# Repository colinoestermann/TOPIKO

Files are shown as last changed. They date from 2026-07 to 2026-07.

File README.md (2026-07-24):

<div align="center">

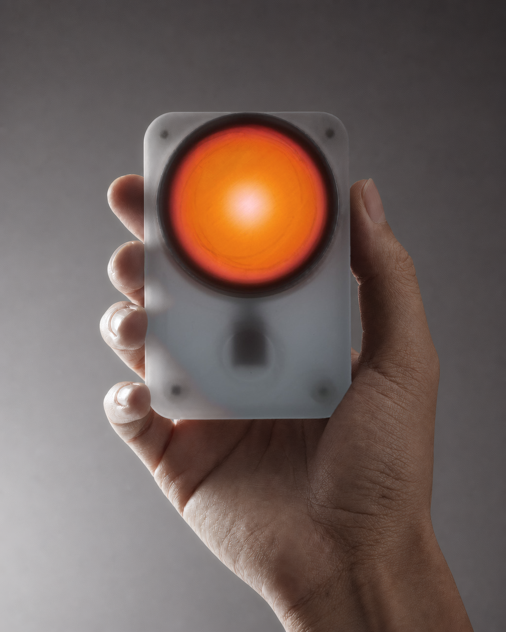
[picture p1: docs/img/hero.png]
TOPIKO


# TOPIKO

**Ein offline Sprachnotiz-Gerät auf Basis von Edge-KI — ohne Cloud, ohne Konto, ohne Abo.**




</div>

---

## Was ist TOPIKO?

TOPIKO ist ein handtellergroßes Gerät, in das man kurze Sprachnotizen spricht. Diese werden **vollständig lokal** in Text umgewandelt und von einem kleinen Sprachmodell in Kategorien wie Termin, To-do, Erinnerung, Idee oder Tagebuch einsortiert — es verlässt kein einziges Byte das eigene Netzwerk. Kein Cloud-Dienst, kein Mikrofon, das dauerhaft mithört, keine Konten.

Das Projekt entstand im Rahmen einer Masterarbeit zum Thema *„Edge-KI als nachhaltige Alternative zu Cloud-KI"* und ist als offene Bauanleitung gedacht: 3D-Daten, Firmware, Serversoftware und Dokumentation sind frei verfügbar.

Das Interface ist bewusst **wortlos**: Das Display strahlt durch eine transluzente Gehäuseschicht, ein weicher Lichtkörper reagiert in Echtzeit auf die Stimme, und Zustände werden nur über Farbe und Bewegung ausgedrückt.

## Systemüberblick

TOPIKO besteht aus zwei Komponenten, die über WLAN miteinander sprechen:

| Komponente | Hardware | Aufgabe |
|---|---|---|
| **Handheld** | Waveshare ESP32-S3-Touch-AMOLED-1.75 | Aufnahme per Touch, Visualisierung, Upload der Sprachnotiz |
| **Dock** | Arduino UNO Q (Debian Linux) | Transkription (Whisper) + Klassifizierung (lokales LLM) |

```
   ┌──────────────┐    WLAN / WAV-Upload     ┌────────────────────┐
   │   Handheld    │ ───────────────────────▶ │        Dock         │
   │  ESP32-S3     │                           │     Arduino UNO Q   │
   │  AMOLED,Mikro │ ◀─────────────────────── │  Whisper + LLM      │
   └──────────────┘   JSON-Ergebnis zurück     └────────────────────┘
```

Das Handheld nimmt auf Tastendruck bis zu 20 s Audio auf, legt es in eine lokale Warteschlange und lädt es hoch, sobald das Dock erreichbar ist. Das Dock transkribiert mit `whisper.cpp` und klassifiziert mit einem kleinen, quantisierten Sprachmodell (llama.cpp). Das Ergebnis kommt als JSON zurück und wird am Gerät über einen Kategorie-Farbpuls angezeigt.

## Funktionen

- **100 % offline** — Transkription und Klassifizierung laufen lokal auf dem Dock.
- **Push-to-talk** — Touch halten, sprechen, loslassen. Kein Wake-Word, kein Dauerlauschen.
- **Wortloses Licht-Interface** — der Lichtkörper atmet mit der Stimme; Kategorien und Zustände über Farbe.
- **Robuste Warteschlange** — Notizen werden lokal gepuffert und automatisch hochgeladen, sobald das Dock da ist.
- **Stromsparend** — Deep-Sleep nach Inaktivität, konfigurierter AXP2101-Laderegler.
- **Offene Hardware** — 3D-druckbares Gehäuse, Standard-Bauteile, unter ~100 €.

## Repo-Struktur

```
topiko/
├── firmware/topiko_handheld/   ESP32-S3-Firmware (Arduino) inkl. ES7210/ES8311-Treiber
├── software/                   Dock-Software für den Arduino UNO Q (Flask + Whisper + LLM)
├── models/                     Bezug der KI-Modelle (Whisper + TOPIKO-Sprachmodell) + Download-Skript
├── hardware/
│   ├── 3d/                     Druckbare STL (Gehäuse Ober-/Unterteil)
│   └── cad/                    CAD-Quelldateien (STEP, alle Bauteile)
├── docs/
│   ├── aufbau.md               Hardware-Aufbau: drucken, montieren, flashen
│   ├── software-installation.md  Dock einrichten (Whisper, LLM, App)
│   └── TOPIKO_Anleitung_IKEA.pdf  Bebilderte Kurz-Bauanleitung
└── media/                      Fotos, Renderings, Logo
```

## Schnellstart

1. **Hardware bauen** → [`docs/aufbau.md`](docs/aufbau.md): Gehäuse drucken, Bauteile montieren, Firmware flashen.
2. **Dock einrichten** → [`docs/software-installation.md`](docs/software-installation.md): Whisper + Sprachmodell + App auf dem UNO Q installieren.
3. Handheld einschalten, WLAN/Dock verbinden, Touch halten und sprechen.

## Stückliste (Kurzfassung)

| Bauteil | Hinweis |
|---|---|
| Waveshare ESP32-S3-Touch-AMOLED-1.75 | Handheld-Rechner mit Display, Mikro-Array, Touch, AXP2101 |
| Arduino UNO Q (2 GB) | Dock, führt Whisper + LLM aus |
| LiPo-Akku 3,7 V (~320–500 mAh) | flach, für den mobilen Betrieb |
| Lautsprecher (MX1.25) | Bestätigungstöne |
| TTP223 Touch-Sensor | Auslöser im Gehäuse |
| Gewindeeinsätze M2.5 + Schrauben M2.5×7 | Verschraubung |
| Transluzentes + opakes PLA | Gehäuse (Display scheint durch) |

Detaillierte Liste und Montage: [`docs/aufbau.md`](docs/aufbau.md).

## Lizenz

- **Software / Firmware:** [MIT](LICENSE)
- **Hardware, 3D-Daten, Dokumentation:** [CC BY-SA 4.0](LICENSE-hardware.md)

Kurz: frei nutzen, verändern und weitergeben. Bei Hardware/Doku bitte Namensnennung und Weitergabe unter gleichen Bedingungen.

---

<div align="center">
<sub>TOPIKO — Edge-KI als nachhaltige Alternative zu Cloud-KI.</sub>
</div>

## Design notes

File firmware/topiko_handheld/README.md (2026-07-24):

# TOPIKO Handheld-Firmware — Setup & Test

Board: **Waveshare ESP32-S3-Touch-AMOLED-1.75**
Funktion: Taste → 5 s Aufnahme → WAV per WLAN an das UNO-Q-Dock (`/classify`) → JSON-Ergebnis auf dem AMOLED.

## 1. Dateien in den Sketch-Ordner legen
Dieser Ordner braucht neben `topiko_handheld.ino` noch den ES8311-Treiber aus dem Waveshare-Beispiel:
- `es8311.c` und `es8311.h` aus dem Repo `waveshareteam/ESP32-S3-Touch-AMOLED-1.75`,
  Pfad `examples/Arduino-v3.3.5/examples/08_ES8311/` — beide Dateien hierher kopieren.

## 2. Arduino-IDE
- Boardpaket **arduino-esp32 Core ≥ 3.1.0** (Beispiele sind für 3.3.5).
- Board: **ESP32S3 Dev Module**
- **PSRAM: OPI PSRAM** (zwingend — der Audiopuffer liegt im PSRAM)
- Flash Size: **16MB**, USB CDC On Boot: **Enabled**
- Bibliotheken (Bibliotheksverwalter): **GFX Library for Arduino**, **ArduinoJson** (v7).
  `ESP_I2S` ist Teil des Cores.

## 3. Konfiguration im Sketch ausfüllen
```
#define WIFI_SSID  "DEIN_WLAN"
#define WIFI_PASS  "DEIN_PASSWORT"
#define DOCK_IP    "192.168.2.86"   // IP des UNO Q im selben WLAN
```

## 4. Dock prüfen (läuft bereits)
Der Endpunkt ist auf dem UNO Q aktiv. Schnelltest von einem Rechner im selben Netz:
```
curl -F "audio=@irgendeine_16k_mono.wav" http://192.168.2.86:5000/classify
```
Antwort ist JSON mit `transcript`, `result`, `whisper_time`, `llm_time`.

## 5. Auf dem Board zu verifizieren (kann ich blind nicht testen)
Diese Stellen sind im Code mit `VERIFY` markiert:
1. **Mikrofon-Datenpin (wichtigste Stelle):** Die DI/DO-Benennung ist im Waveshare-Repo widersprüchlich. Wenn die Aufnahme **stumm** ist, in `setup()` bei `i2s.setPins(...)` die Argumente **PIN_DI und PIN_DO tauschen**.
2. **Mikrofon-Typ:** `es8311_microphone_config(h, false)` = analoges Mikro. Falls kein Signal, auf `true` (digital) testen. Sollte das Mic-Array über den **ES7210** laufen, muss dieser zusätzlich initialisiert werden (dann Bescheid geben).
3. **Kanal:** Mono nimmt den linken Kanal (`s[i*2]`). Bei Stille/Rauschen ggf. `s[i*2+1]`.
4. **Mic-Gain:** `MIC_GAIN` (Default 30 dB) bei zu leiser/übersteuerter Aufnahme anpassen.
5. **Auslöser-Taste:** Default ist die **BOOT-Taste (GPIO0)**. Für einen eigenen Gehäuse-Taster `BTN_PIN` auf den verwendeten GPIO setzen.
6. **AMOLED-Stromversorgung:** Das Hello-World-Beispiel des Boards treibt das Display ohne PMU-Code, daher kein AXP2101-Init nötig. Falls das Display dunkel bleibt, AXP2101 per `XPowersLib` `power.begin(Wire, AXP2101_SLAVE_ADDRESS, 15, 14)` ergänzen.

## 6. Erwarteter Ablauf
Start → „Bereit · Taste = Notiz" → Taste drücken → „Aufnahme… sprich jetzt" (5 s) → „Verarbeite…" (~50 s) → Anzeige von `type`, `title` und Transkript.

## Status
Firmware ist vollständig geschrieben, aber **noch nicht auf dem Gerät getestet** (kein Board im Zugriff). Erwartbar treffsicher: WLAN, Multipart-Upload, JSON, Display. Erfahrungsgemäß braucht der **Audio-Aufnahmepfad** (Punkt 1–3) eine kurze Hardware-Iteration.

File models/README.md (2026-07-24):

# KI-Modelle

Das **Dock** benötigt zwei Modelle. Beide sind zu groß fürs git-Repo und werden
separat geladen. Das Skript [`download-models.sh`](download-models.sh) holt beide
an die richtigen Stellen.

## 1. Whisper — Transkription

`ggml-small-q4_0.bin`, ein Standardmodell von whisper.cpp. Wird direkt über
whisper.cpp geladen:

```bash
cd ~/whisper.cpp && ./models/download-ggml-model.sh small-q4_0
```

Zielpfad: `~/whisper.cpp/models/ggml-small-q4_0.bin`

## 2. TOPIKO-Sprachmodell — Klassifizierung

`LFM2.5-350M-TOPIKO-Q4_K_M.gguf` — ein auf **LFM2.5-350M** feinjustiertes,
quantisiertes Sprachmodell, das den transkribierten Text in die TOPIKO-Kategorien
(Termin, To-do, Erinnerung, Idee, Tagebuch) einsortiert. Gehostet auf Hugging Face:

> **➡ Download: https://huggingface.co/colin18054/TOPIKO-LFM2.5-350M-GGUF**

Nach dem Download ablegen unter:

```
~/models/LFM2.5-350M-TOPIKO-Q4_K_M.gguf
```

Der Pfad entspricht `GGUF_PATH` in [`../software/topiko_uno_q_app.py`](../software/topiko_uno_q_app.py).

## Beides auf einmal laden

```bash
bash download-models.sh
```

> Vorher im Skript den Platzhalter `HF_REPO` durch das echte Hugging-Face-Repo ersetzen.

---

## Für Maintainer: Modell auf Hugging Face veröffentlichen

Das feinjustierte Modell liegt auf dem Dock unter `~/models/`. Von dort einmalig
hochladen:

```bash
pip install -U "huggingface_hub[cli]"
huggingface-cli login                     # Token von huggingface.co/settings/tokens (Rolle: Write)
huggingface-cli upload colin18054/TOPIKO-LFM2.5-350M-GGUF \
  ~/models/LFM2.5-350M-TOPIKO-Q4_K_M.gguf \
  LFM2.5-350M-TOPIKO-Q4_K_M.gguf
```

Das Modell ist bereits veröffentlicht unter
`https://huggingface.co/colin18054/TOPIKO-LFM2.5-350M-GGUF`.

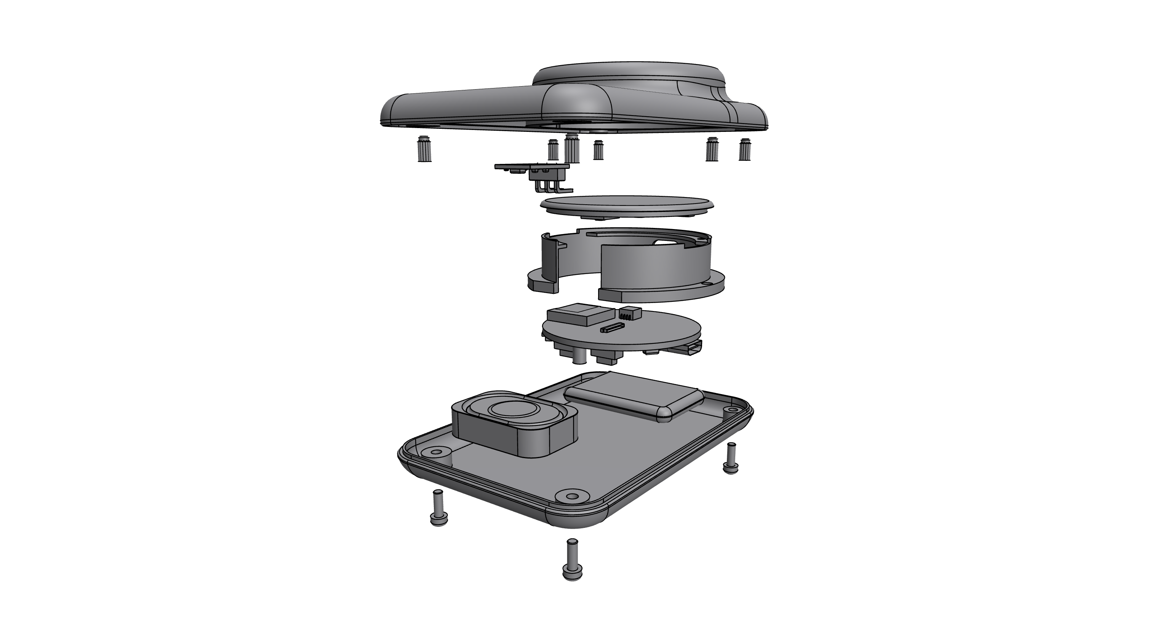
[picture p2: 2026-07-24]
docs/img/Explosionsansicht.png

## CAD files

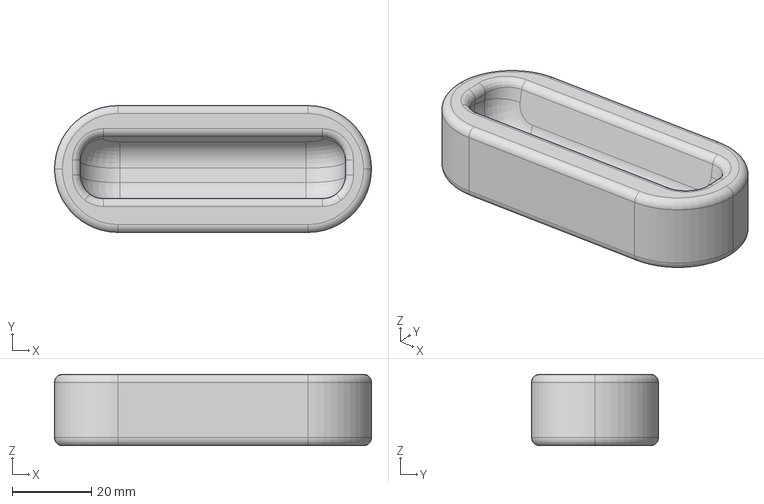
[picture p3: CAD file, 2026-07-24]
hardware/3d/TOPIKO_DOCK_1.0.step
80.0 x 32.0 x 18.0 mm

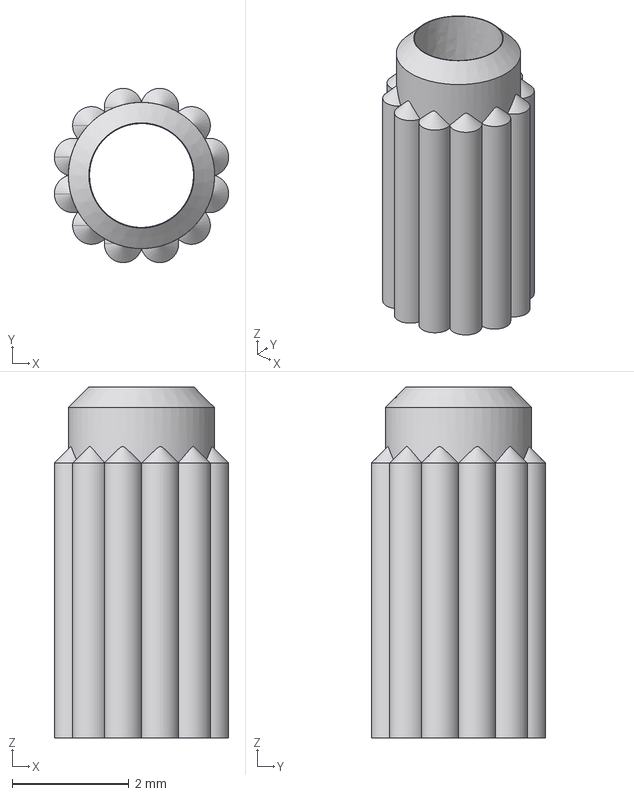
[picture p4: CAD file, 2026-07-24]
hardware/cad/Gewindeeinsatz_M2.5.step
2.98 x 2.98 x 6.00 mm

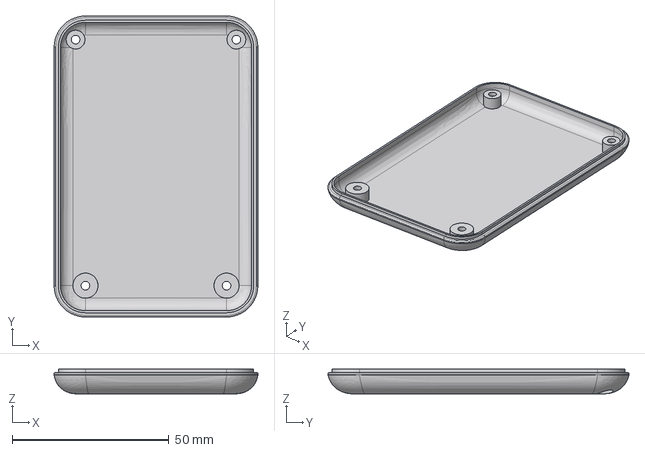
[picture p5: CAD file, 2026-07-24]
hardware/3d/Unterteil.step
65.0 x 96.0 x 7.90 mm

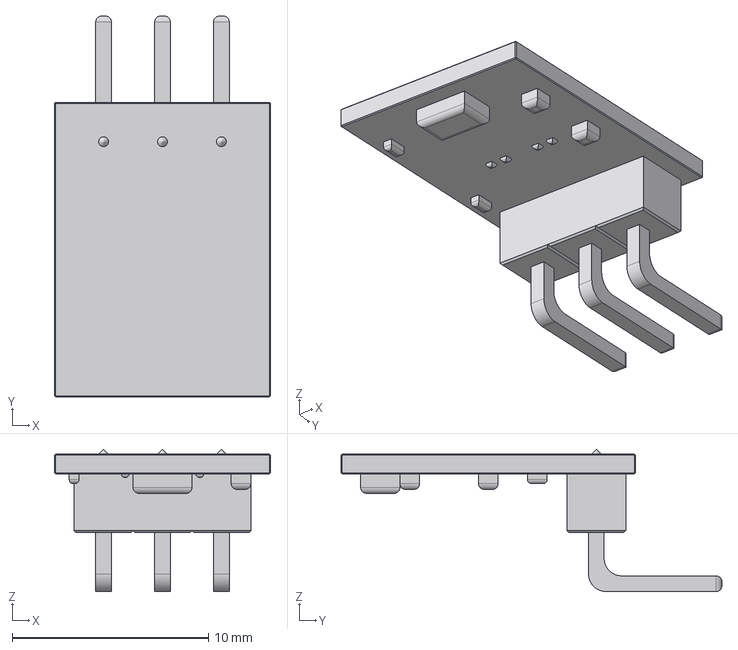
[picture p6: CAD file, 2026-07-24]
hardware/cad/Touchsensor.step
11.0 x 19.4 x 7.24 mm

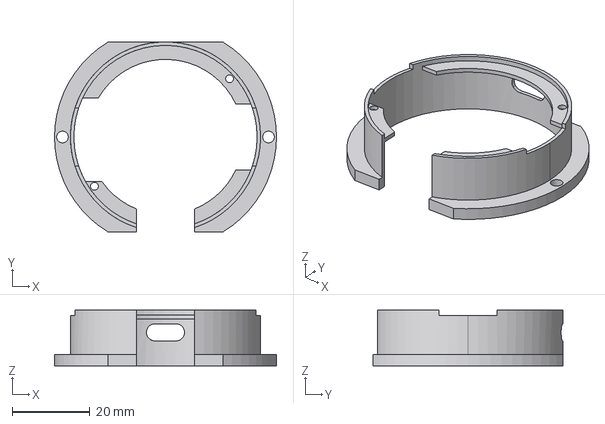
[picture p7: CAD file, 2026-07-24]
hardware/3d/Gehäuseeinsatz.step
57.2 x 49.0 x 14.3 mm

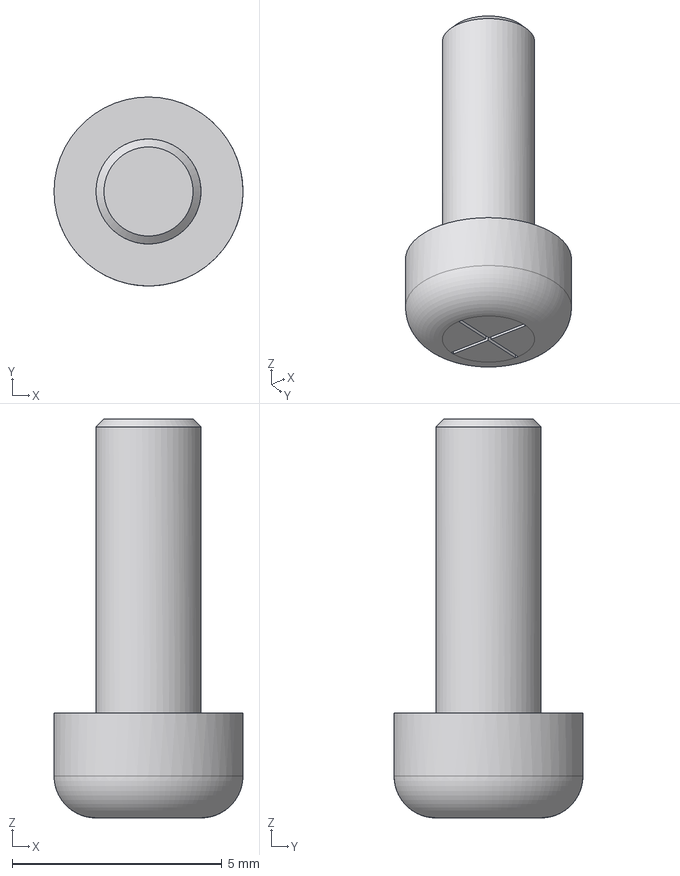
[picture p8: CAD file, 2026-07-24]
hardware/cad/Schraube_M2.5x7.step
4.50 x 4.50 x 9.50 mm

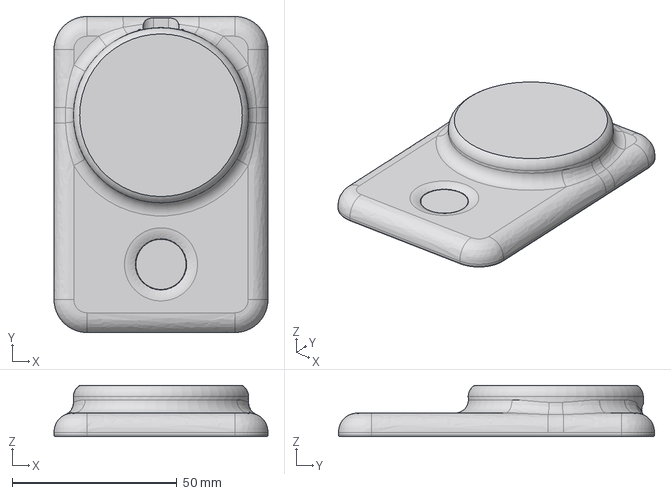
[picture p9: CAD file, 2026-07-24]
hardware/3d/Oberteil.step
65.0 x 96.0 x 15.6 mm

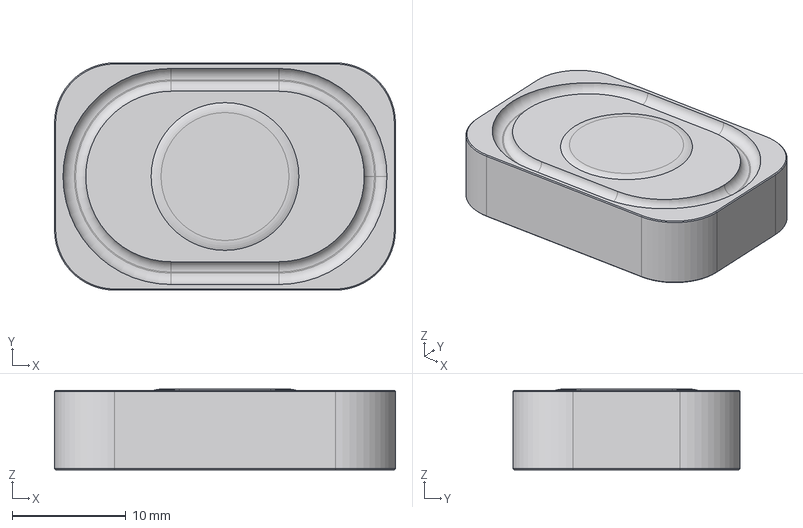
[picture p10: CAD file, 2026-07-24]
hardware/cad/Lautsprecher.step
30.0 x 20.0 x 7.10 mm

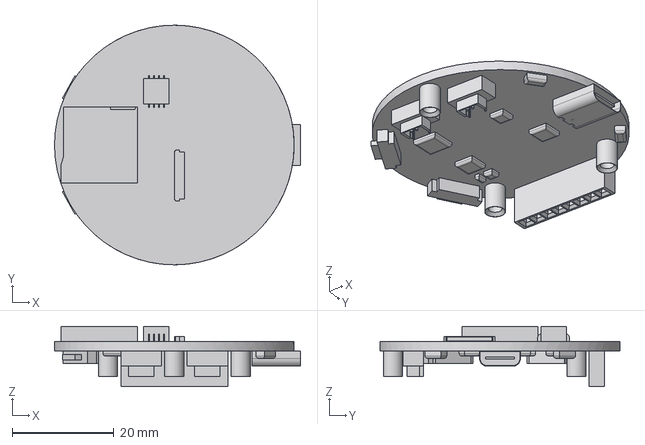
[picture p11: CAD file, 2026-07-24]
hardware/cad/ESP-Board.step
48.2 x 47.0 x 11.8 mm

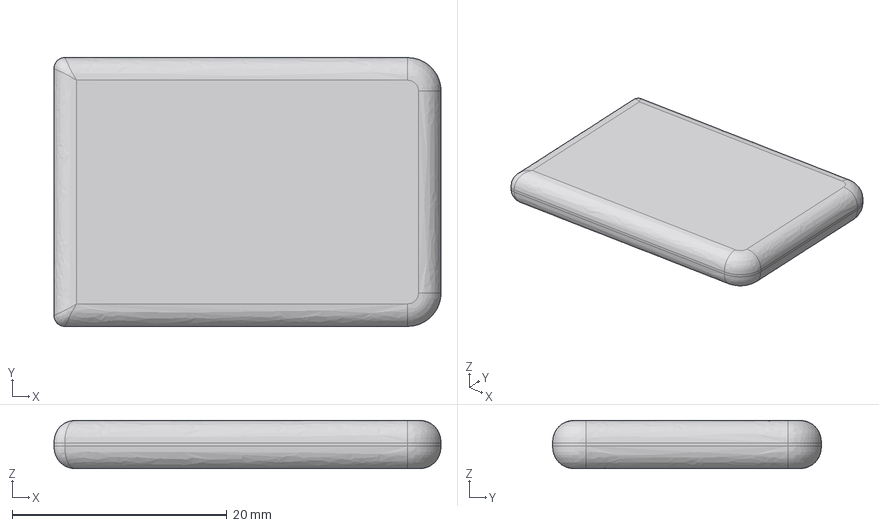
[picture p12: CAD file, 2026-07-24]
hardware/cad/Akku.step
36.0 x 25.0 x 4.50 mm

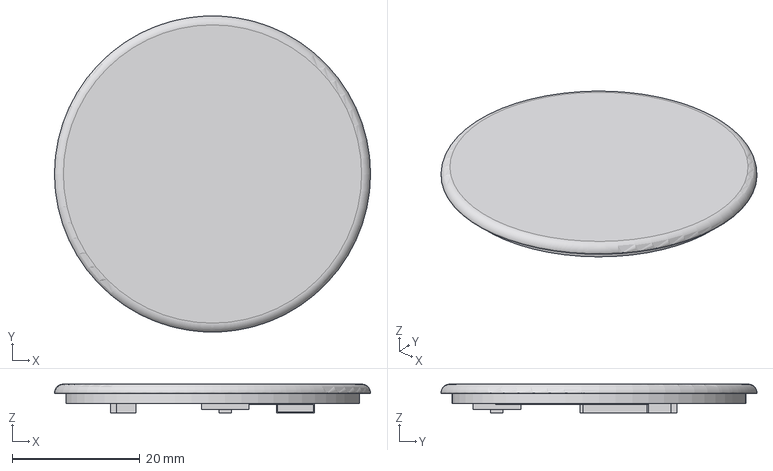
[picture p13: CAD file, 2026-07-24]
hardware/cad/Display.step
49.5 x 49.5 x 4.50 mm

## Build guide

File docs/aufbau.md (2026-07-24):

# TOPIKO — Hardware-Aufbau

Diese Anleitung beschreibt den Bau des **Handhelds**. Die Einrichtung des Docks (Arduino UNO Q) ist in [`software-installation.md`](software-installation.md) beschrieben. Eine bebilderte Kurzfassung liegt als [`TOPIKO_Anleitung_IKEA.pdf`](TOPIKO_Anleitung_IKEA.pdf) bei.

## Stückliste

| # | Bauteil | Details |
|---|---|---|
| 1 | **Waveshare ESP32-S3-Touch-AMOLED-1.75** | 1,75″ rundes AMOLED (466×466), Dual-Mikrofon-Array (ES7210), Lautsprecher-Codec (ES8311), Touch, AXP2101-Laderegler, microSD |
| 2 | **LiPo-Akku 3,7 V** | flach, ~320–500 mAh, MX1.25-Stecker (passend zum Board-Akkuanschluss) |
| 3 | **Lautsprecher** | kleiner 8-Ω-Lautsprecher mit MX1.25-Stecker |
| 4 | **TTP223 Touch-Sensor** | kapazitiver Taster, an den 8-Pin-Header (Pin „16") |
| 5 | **Gewindeeinsätze M2.5** + **Schrauben M2.5×7** | zum Verschrauben der Gehäusehälften |
| 6 | **Transluzentes PLA** | 1–2 mm Wandstärke über dem Display (Display scheint durch) |
| 7 | **Opakes PLA** | Gehäusekörper |
| 8 | **microSD-Karte** (optional) | größere Aufnahme-Warteschlange; sonst interner Flash (FFat) |

Richtwert Materialkosten: ~80–100 €.

## 1. Gehäuse drucken

Die druckbaren Teile liegen in [`../hardware/3d/`](../hardware/3d/) als STL, die editierbaren Quelldateien in [`../hardware/cad/`](../hardware/cad/) als STEP.

- **Oberteil** (`TOPIKO_4.0_Oberteil.stl`): über dem Display **transluzentes PLA**, 1–2 mm Wand über dem Displaybereich, damit das Licht diffus durchscheint.
- **Unterteil** (`TOPIKO_4.0_Unterteil.stl`): **opakes PLA**.
- Empfehlung: 0,12–0,16 mm Schichthöhe, keine Stützen nötig, Displayfläche nach oben drucken.

Gewindeeinsätze M2.5 nach dem Druck mit dem Lötkolben einschmelzen.

Explosionsansicht und Teile: siehe [`img/Explosionsansicht.png`](img/Explosionsansicht.png) und [`img/topiko-aufbauanleitung-teile-v1.png`](img/topiko-aufbauanleitung-teile-v1.png).

## 2. Bauteile montieren

1. **Lautsprecher** in den Halter im Unterteil setzen, MX1.25-Stecker in den Lautsprecher-Anschluss des Boards.
2. **Akku** einlegen (doppelseitiges Klebepad), MX1.25-Stecker an den Akkuanschluss. **Polung prüfen** — falsche Polung zerstört das Board.
3. **Touch-Sensor (TTP223)** ins Oberteil setzen, sodass der gedruckte Nippel bzw. die Gehäuseflanke den Sensor auslöst. Verdrahtung an den 8-Pin-Header:

   | TTP223 | Board 8-Pin-Header |
   |--------|--------------------|
   | VCC | 3V3 |
   | GND | GND |
   | I/O (Signal) | Pin **16** |

   Der Sensor ist **aktiv HIGH**. Ohne angeschlossenen Sensor liegt Pin 16 über einen internen Pulldown fest auf LOW (kein Fehlauslösen).
4. **Board** einsetzen, Display nach oben zur transluzenten Fläche ausrichten.
5. Gehäusehälften verschrauben (M2.5×7).

## 3. Firmware flashen

Die Firmware liegt in [`../firmware/topiko_handheld/`](../firmware/topiko_handheld/). Die ES7210-/ES8311-Treiber sind bereits enthalten.

### Arduino-IDE einrichten

- **Boardpaket:** `arduino-esp32` Core **≥ 3.1.0** (getestet mit 3.3.10).
- **Board:** *ESP32S3 Dev Module*
- **PSRAM:** *OPI PSRAM* (zwingend — der Bildpuffer liegt teils im PSRAM)
- **Flash Size:** *16MB*
- **Partition Scheme:** *16M Flash (3MB APP/9.9MB FATFS)*
- **USB CDC On Boot:** *Enabled*
- **Bibliotheken** (Bibliotheksverwalter): *GFX Library for Arduino*, *ArduinoJson* (v7), *XPowersLib*. `ESP_I2S` ist Teil des Cores.

### WLAN / Dock konfigurieren

Im Sketch bzw. in einer optionalen `secrets.h` (gleicher Ordner) eintragen:

```c
#define WIFI_SSID  "DEIN_WLAN"
#define WIFI_PASS  "DEIN_PASSWORT"
```

Das Handheld verbindet sich mit zwei WLANs (in dieser Reihenfolge):

- **`TOPIKO` / `topiko2026`** — der Hotspot des Docks (fest im Code, für den mobilen/Ausstellungsbetrieb), Dock unter `10.42.0.1`.
- **Dein Heim-WLAN** aus `WIFI_SSID`/`WIFI_PASS`, Dock unter `192.168.2.86` (Adresse ggf. im Sketch anpassen: `DOCK_HOST_HOME`).

### Kompilieren & Flashen (Kommandozeile, optional)

```bash
arduino-cli compile --upload -p /dev/cu.usbmodemXXXX \
  --fqbn "esp32:esp32:esp32s3:PSRAM=opi,FlashSize=16M,PartitionScheme=app3M_fat9M_16MB,CDCOnBoot=cdc" \
  firmware/topiko_handheld
```

## 4. Bedienung

- **Aufnahme:** Touch halten → sprechen → loslassen. Der Lichtkörper schrumpft während des Sprechens als Feedback.
- **Ergebnis:** Kommt vom Dock ein Ergebnis zurück, pulst die Kategorie-Farbe (Termin = blau, To-do = orange, Erinnerung = lila, Idee = gelb, Tagebuch = grün).
- **Akkuwarnung:** Unter 20 % färbt sich der Ruhezustand leicht rot, unter 10 % kräftig dunkelrot.
- **Deep-Sleep:** Nach 5 Minuten Inaktivität im Akkubetrieb; Aufwecken durch Berühren des Touch-Sensors.

## Hinweise & Troubleshooting

- **Mikrofon nimmt nichts auf:** Das Mikro-Array hängt am linken I2S-Kanal (ADC1). Der ES7210 muss die volle „start"-Sequenz durchlaufen (in der Firmware enthalten) — sonst bleibt der Analogteil stumm. Im seriellen Log erscheint beim Boot `[MIC] ES7210 init ...`.
- **Kein Laden / falscher Ladestand:** Der AXP2101 wird per XPowersLib initialisiert (`disableTSPinMeasure()` ist gesetzt, da kein Akku-NTC verbaut ist). Serielles Log: `[BAT] Akku erkannt, …%`.
- **Display bleibt dunkel:** PSRAM auf *OPI* gestellt? Ohne PSRAM scheitert die Pufferzuweisung.

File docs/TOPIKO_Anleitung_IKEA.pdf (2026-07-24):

# TOPIKO

## offline voice companion

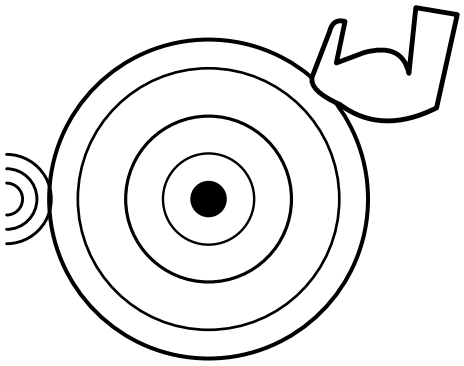
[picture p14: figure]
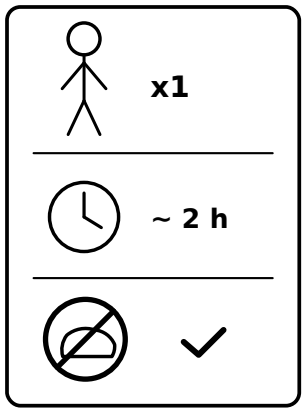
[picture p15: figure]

1 | TOPIKO

!

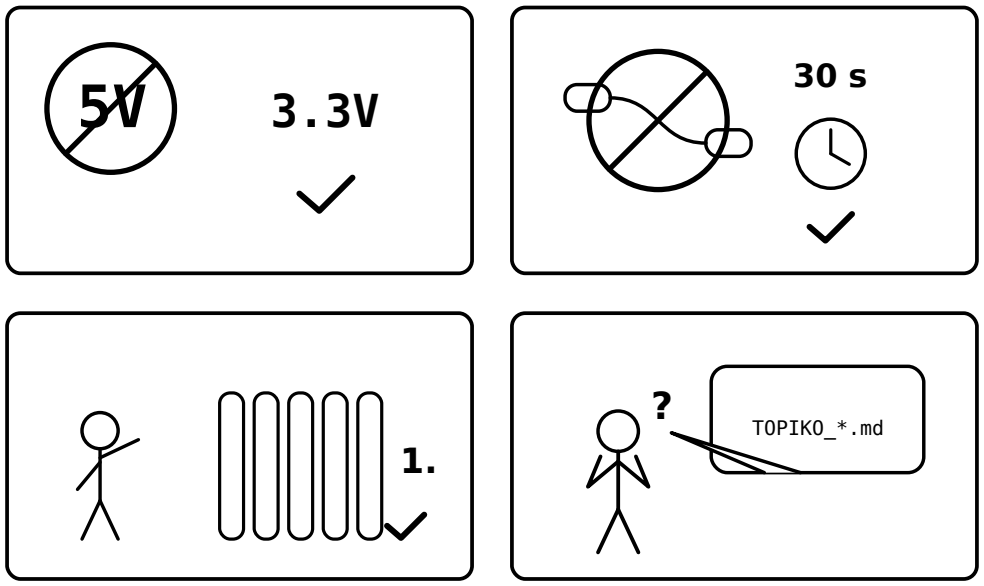
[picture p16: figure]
TOPIKO_*.md

ESP32-S3 AMOLED 1.75″
x1

VCC
I/O

GND

TTP223
x1

microSD 16 GB
x1

3x F-F
x3

3.7V

LiPo 3.7V JST
x1

Speaker 8Ω
x1

USB-C
x2

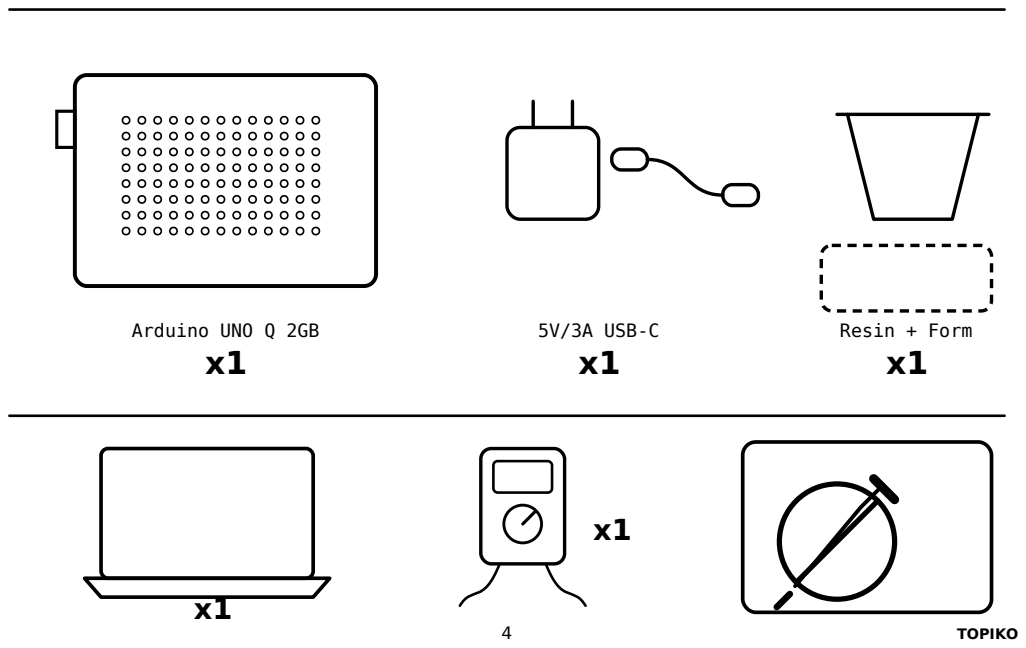
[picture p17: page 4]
Arduino UNO Q 2GB x1; 5V/3A USB-C x1; Resin + Form x1

1

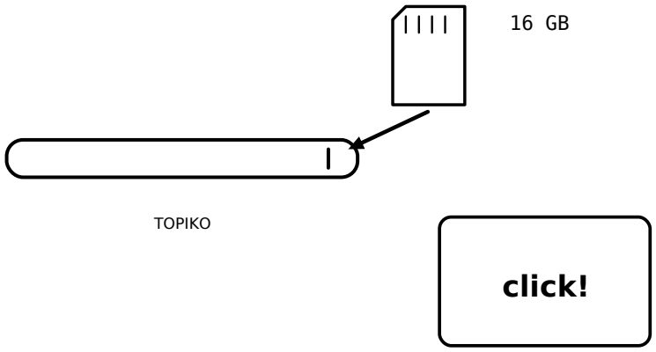
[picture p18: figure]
TOPIKO; click!

2

18

17

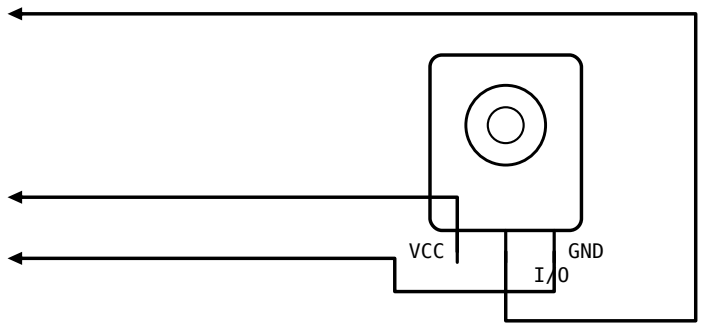
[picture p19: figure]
VCC; GND

16

RX

TX

3.3V G

5V

TOPIKO
5V

3.3V

3

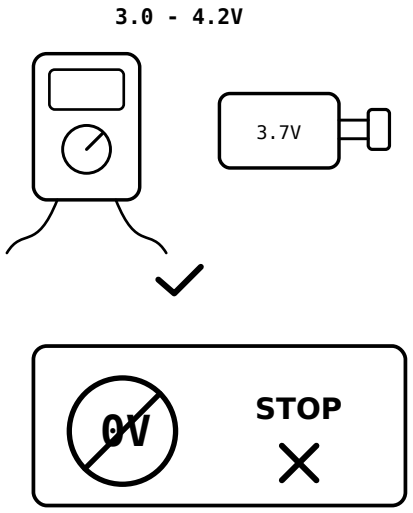
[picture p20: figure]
STOP

JST: rot = +

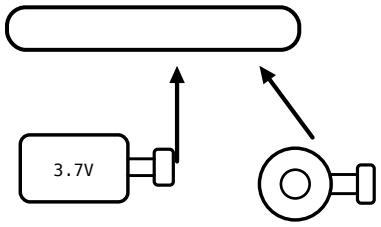
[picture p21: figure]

4

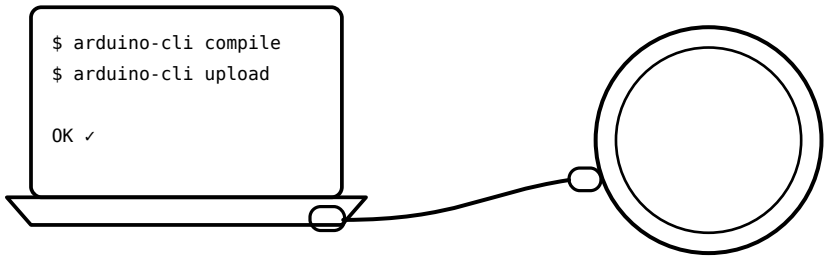
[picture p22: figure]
$ arduino-cli compile $ arduino-cli upload

### github.com/…/topiko → Firmware/topiko_handheld/

esp32:esp32:esp32s3 · PSRAM=opi · FlashSize=16M · app3M_fat9M

5

## "TOPIKO"

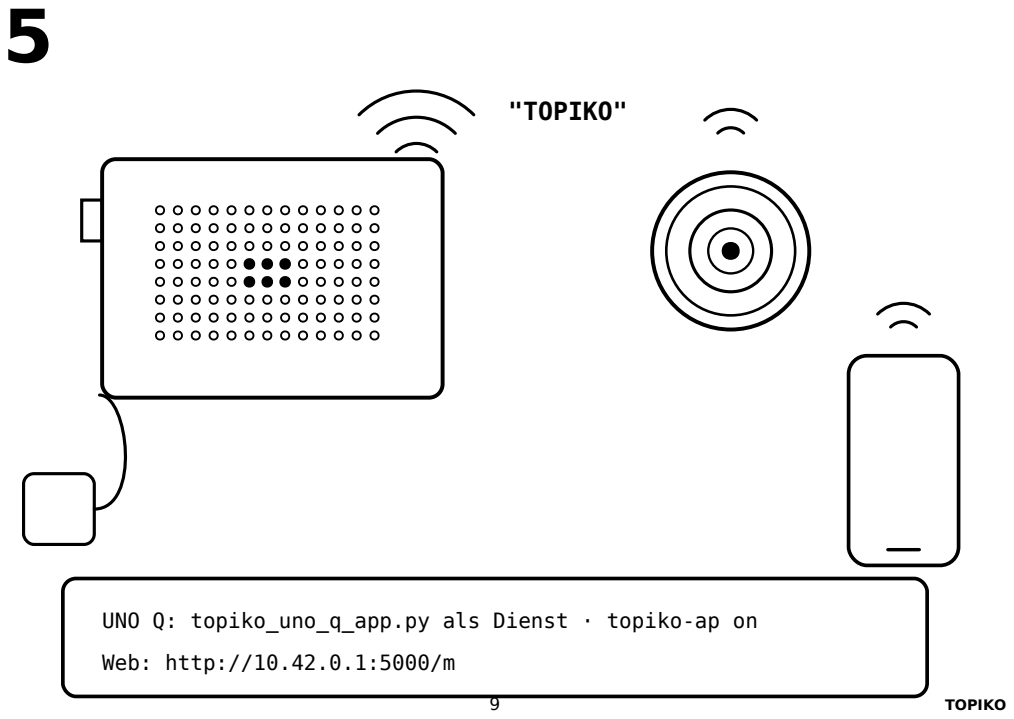
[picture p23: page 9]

UNO Q: topiko_uno_q_app.py als Dienst · topiko-ap on
Web: http://10.42.0.1:5000/m

6

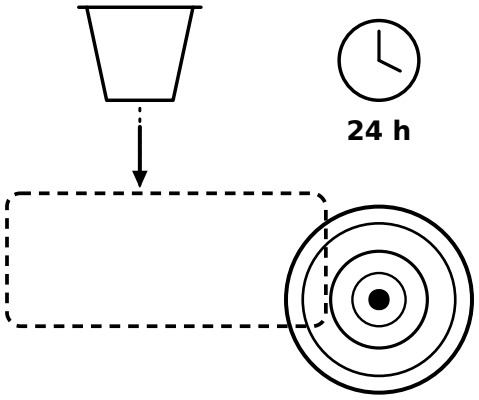
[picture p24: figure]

✓

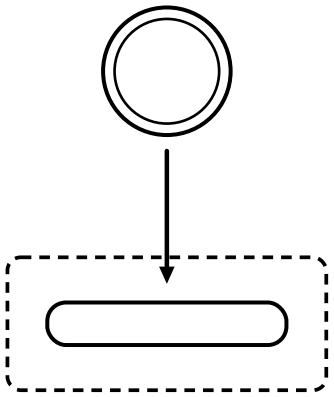
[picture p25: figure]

●

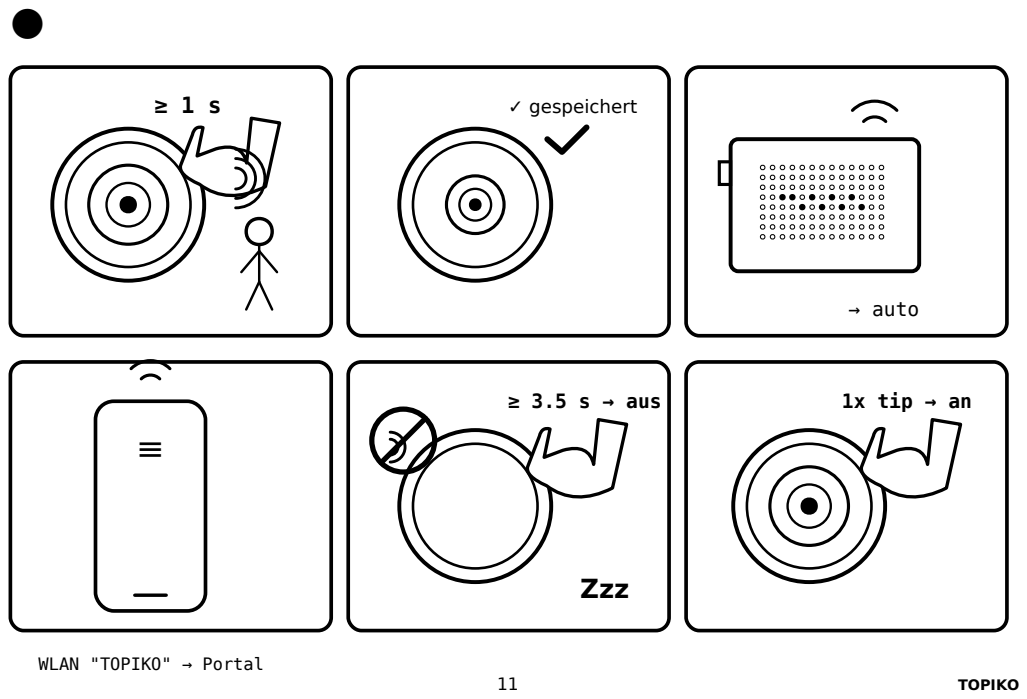
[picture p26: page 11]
✓ gespeichert; → auto; ≥ 3.5 s → aus; Zzz; 1x tip → an

WLAN "TOPIKO" → Portal

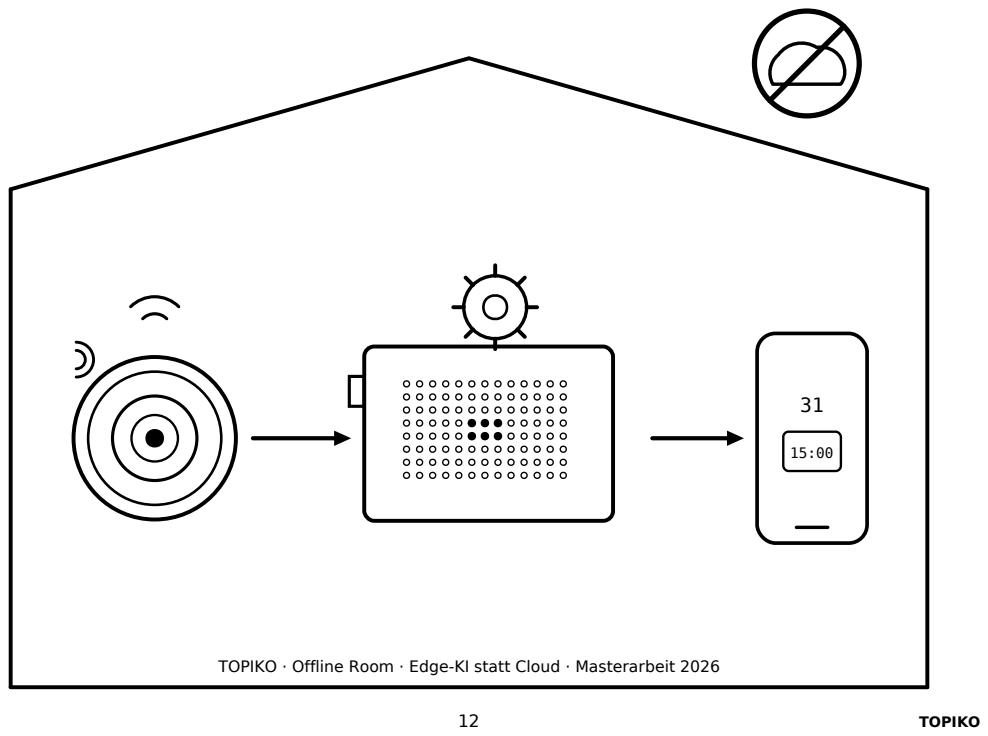
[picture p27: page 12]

TOPIKO · Offline Room · Edge-KI statt Cloud · Masterarbeit 2026

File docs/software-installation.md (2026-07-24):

# TOPIKO — Dock-Software installieren

Das **Dock** (Arduino UNO Q, Debian Linux) übernimmt die KI-Verarbeitung: Es empfängt die WAV-Aufnahmen des Handhelds, transkribiert sie mit **whisper.cpp** und klassifiziert den Text mit einem kleinen, lokalen Sprachmodell über **llama-cpp-python**. Alles läuft offline.

Die Software liegt in [`../software/`](../software/):

- `topiko_uno_q_app.py` — der Flask-Server (Endpunkte `/upload`, `/classify`, `/api/results`, Weboberfläche).
- `topiko_mobile.py` — mobiles Web-Frontend / Captive-Portal-Modul (wird vom Hauptserver eingebunden).

## Voraussetzungen

- Arduino UNO Q mit Debian Linux (oder ein anderer Linux-Rechner, z. B. Raspberry Pi 5).
- Python 3.10+.
- Ein WLAN, in dem Handheld und Dock sich sehen — oder das Dock als Hotspot (siehe unten).

## 1. Systempakete

```bash
sudo apt update
sudo apt install -y git build-essential cmake python3-pip python3-venv alsa-utils
```

## 2. whisper.cpp bauen + Modell laden

Der Server erwartet die Binary unter `~/whisper.cpp/build/bin/whisper-cli` und das Modell unter `~/whisper.cpp/models/ggml-small-q4_0.bin`.

```bash
cd ~
git clone https://github.com/ggerganov/whisper.cpp
cd whisper.cpp
cmake -B build && cmake --build build --config Release -j
# Modell (klein, quantisiert) herunterladen:
./models/download-ggml-model.sh small-q4_0
```

## 3. Sprachmodell (LLM) bereitstellen

Der Server klassifiziert mit einem für TOPIKO feinjustierten, quantisierten Modell:

```
~/models/LFM2.5-350M-TOPIKO-Q4_K_M.gguf
```

Das Modell ist auf **Hugging Face** gehostet — Download-Link und Details stehen in [`../models/README.md`](../models/README.md). Der Zielpfad entspricht `GGUF_PATH` in `topiko_uno_q_app.py`.

> **Tipp:** Beide Modelle (Whisper + Sprachmodell) auf einmal laden mit
> [`../models/download-models.sh`](../models/download-models.sh).

## 4. Python-Abhängigkeiten

```bash
cd ~/topiko            # Ordner mit topiko_uno_q_app.py + topiko_mobile.py
python3 -m venv .venv
source .venv/bin/activate
pip install -r requirements.txt
```

> `llama-cpp-python` wird beim Installieren aus dem Quellcode gebaut — das kann auf dem UNO Q einige Minuten dauern.

## 5. Audiogerät (nur für lokale Server-Aufnahme)

Für den optionalen serverseitigen Aufnahme-Button nutzt die App `arecord`. Das ALSA-Gerät ist in der Datei gesetzt (`ALSA_DEVICE`). Verfügbare Geräte prüfen:

```bash
arecord -L
```

Für den normalen Handheld-Betrieb (Upload per WLAN) wird kein Mikrofon am Dock benötigt.

## 6. Server starten

```bash
source .venv/bin/activate
python3 topiko_uno_q_app.py
```

Der Server läuft auf **Port 5000**. Beim Start gibt er die IP-Adresse aus. Schnelltest von einem anderen Rechner im selben Netz:

```bash
curl -F "audio=@test_16k_mono.wav" http://<DOCK-IP>:5000/classify
```

Antwort ist JSON mit `transcript`, `result`, `whisper_time`, `llm_time`. Der Status ist auch im Browser unter `http://<DOCK-IP>:5000/health` einsehbar.

## 7. Automatisch starten (optional, systemd)

```ini
# /etc/systemd/system/topiko.service
[Unit]
Description=TOPIKO Dock
After=network-online.target

[Service]
User=<dein-user>
WorkingDirectory=/home/<dein-user>/topiko
ExecStart=/home/<dein-user>/topiko/.venv/bin/python3 topiko_uno_q_app.py
Restart=always

[Install]
WantedBy=multi-user.target
```

```bash
sudo systemctl enable --now topiko
```

## 8. Dock als Hotspot (optional, mobiler Betrieb)

Damit das Handheld ohne vorhandenes WLAN funktioniert, kann das Dock einen Hotspot aufspannen — das Handheld sucht fest nach `TOPIKO` / `topiko2026` (Dock dann unter `10.42.0.1`):

```bash
sudo nmcli device wifi hotspot ssid TOPIKO password topiko2026 ifname wlan0
```

## Datenablage

Aufnahmen und Ergebnisse liegen unter `~/topiko_data/` (`audio/` + `notes.json`). Nach einem Neustart werden unterbrochene Verarbeitungen automatisch wieder eingereiht.

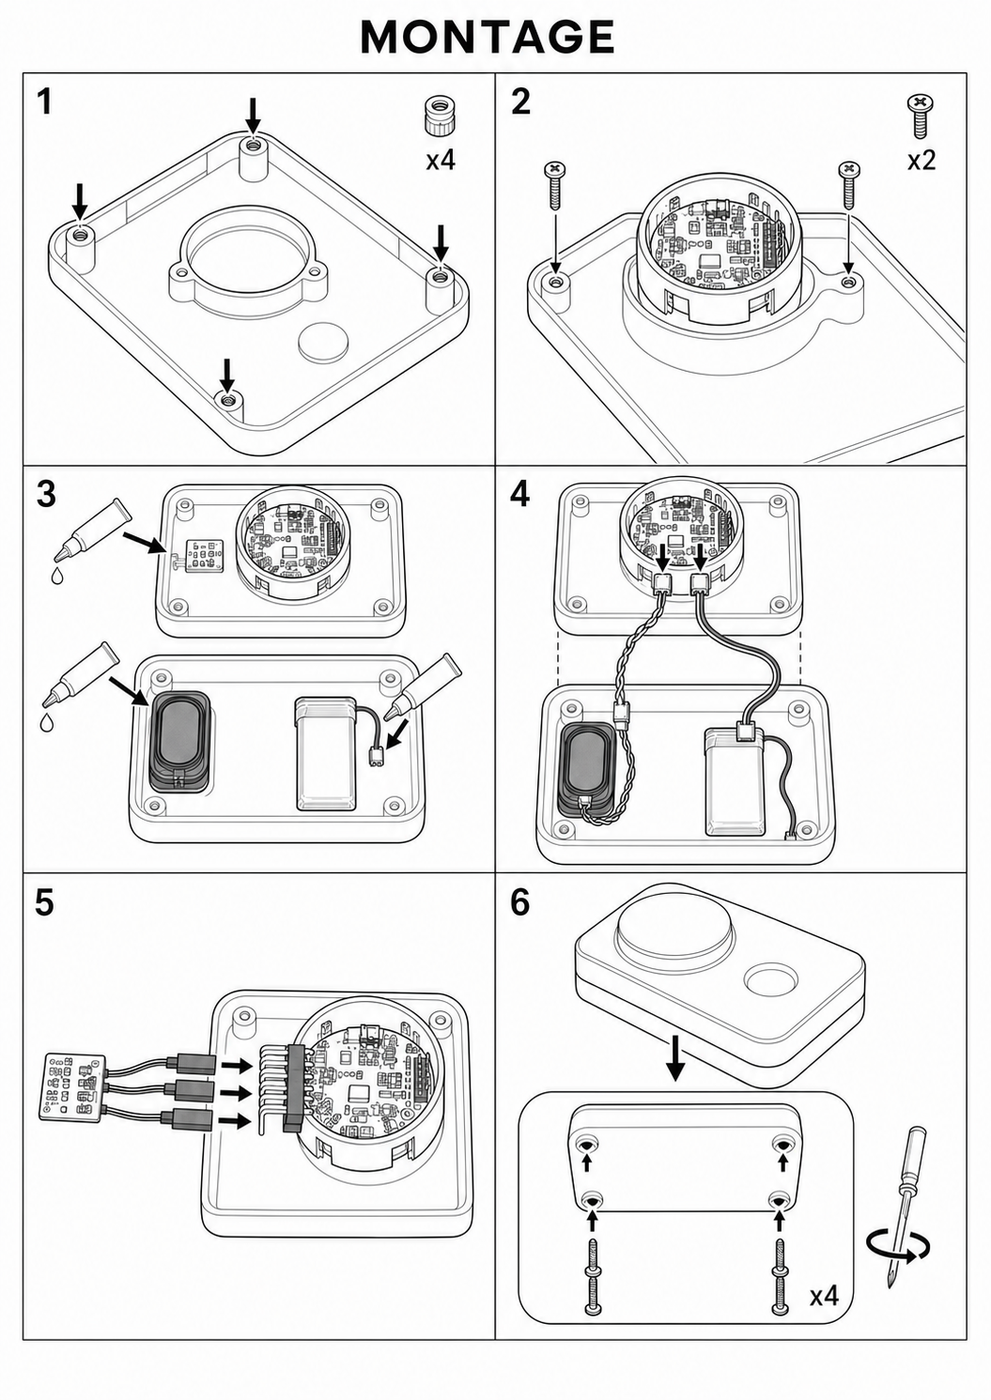
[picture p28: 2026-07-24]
docs/img/topiko-aufbauanleitung-montage-v3.png

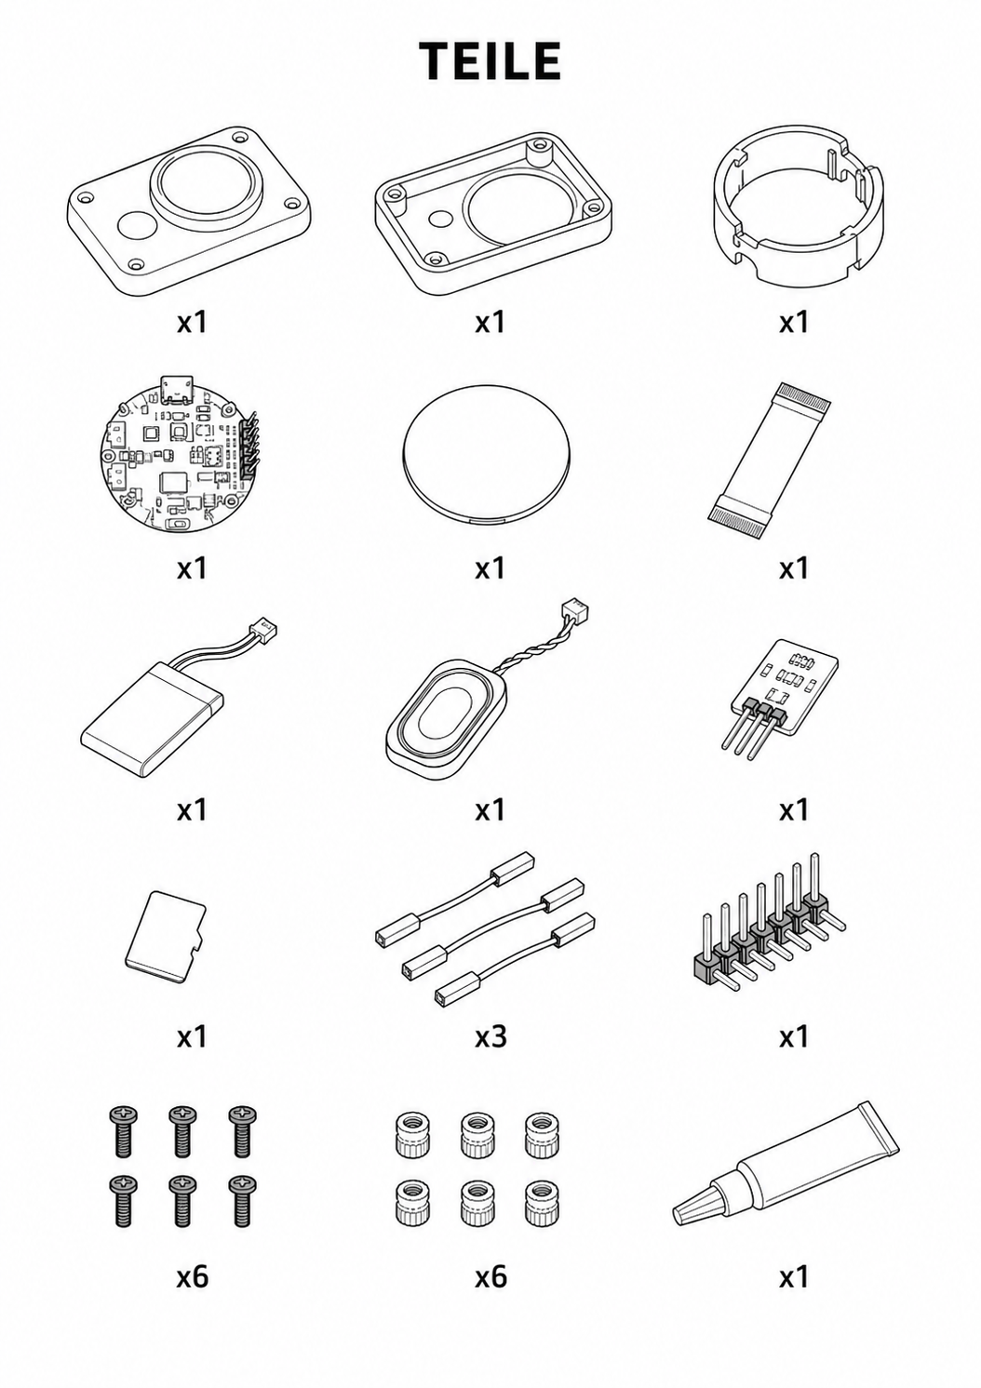
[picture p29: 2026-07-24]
docs/img/topiko-aufbauanleitung-teile-v1.png

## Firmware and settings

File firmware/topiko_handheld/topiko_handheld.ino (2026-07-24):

/**
 * TOPIKO — Handheld-Firmware v3 (Waveshare ESP32-S3-Touch-AMOLED-1.75)
 * ---------------------------------------------------------------------
 * Reines Form-und-Farbe-Interface (Display strahlt durch Resin, KEIN Text):
 *   - Bildschirmfuellende, weichkantige Herz-Abstraktion mit Lub-dub-Pochen
 *   - Mikrofon ist DAUERHAFT offen: das Herz reagiert immer in Echtzeit
 *     auf den Raumklang (Atmen der Form mit dem Pegel)
 *   - Zustaende nur ueber Farbe/Bewegung:
 *       mint, ruhig        = bereit
 *       orange, groesser   = Aufnahme (Taste gehalten), pulsiert mit Stimme
 *       violett, unruhig   = speichert / laedt hoch / Dock rechnet
 *       Kategorie-Farbpuls = Ergebnis zurueckgekommen (termin=blau, todo=orange,
 *                            erinnerung=lila, idee=gelb, tagebuch=gruen)
 *       rot, hektisch      = Fehler (zu kurz / Speicher voll / Mikro stumm)
 *
 * Pipeline wie v2: Push-to-talk -> FFat-Warteschlange -> Upload zum Dock,
 * sobald erreichbar -> JSON-Ergebnisse zurueck aufs Geraet (/done.jsonl,
 * spaeter NFC-Sync ans iPhone).
 *
 * Hardware-Erkenntnis: Das Mikrofon-Array haengt am ES7210-ADC (I2C 0x40),
 * der ES8311 bedient nur den Lautsprecher. I2S: dout=8 (ES8311), din=10 (ES7210).
 *
 * Board: ESP32S3 Dev Module, PSRAM: OPI PSRAM, Flash 16MB,
 *   Partition: 3MB APP / 9.9MB FATFS, USB CDC On Boot: Enabled.
 */

#include <WiFi.h>
#include <WiFiMulti.h>
#include <HTTPClient.h>
#include <Wire.h>
#include <ArduinoJson.h>
#include <ESP_I2S.h>
#include <FFat.h>
#include <SD_MMC.h>   // 16-GB-TF-Karte des Boards: CLK=2, CMD=1, D0=3 (1-bit)
#include <math.h>
#include "Arduino_GFX_Library.h"
#include "es8311.h"
#include "es7210.h"
#include "esp_sleep.h"    // ADC des Mikrofon-Arrays (eigener Chip, I2C 0x40)
#include "esp_heap_caps.h" // internes DMA-RAM fuer den Display-Push
#define XPOWERS_CHIP_AXP2101
#include "XPowersLib.h"   // AXP2101: Akku-Erkennung, Laden, Fuel Gauge
#include "blob_types.h"

// 5 min Inaktivitaet -> Deep Sleep; Aufwachen durch Beruehren des Touch-Buttons (GPIO 16)
void powerOff() {
  Serial.println("[PWR] 5 min inaktiv -> Deep Sleep");
  extern Arduino_CO5300 *gfx;
  extern XPowersAXP2101 power;
  extern bool pmuOk;
  digitalWrite(46, LOW);                    // PA (Lautsprecher) aus
  gfx->fillScreen(0x0000);
  gfx->displayOff();
  delay(50);
  // WICHTIG: Deep Sleep legt nur den ESP32-S3 schlafen. Die Audio-Rail ALDO1
  // (ES8311 + ES7210 + Mikro-Array-Bias + Lautsprecher-PA) laeuft am AXP2101
  // sonst weiter und leert den Akku im "Aus"-Zustand. Rail vor dem Schlafen kappen.
  if (pmuOk) power.disableALDO1();
  while (digitalRead(16) == HIGH) delay(20); // warten bis Finger weg, sonst sofortiger Wake
  delay(200);
  esp_sleep_enable_ext0_wakeup(GPIO_NUM_16, 1);  // Touch = HIGH weckt auf
  esp_deep_sleep_start();
}

fs::FS *store = &FFat;   // aktives Dateisystem: SD bevorzugt, FFat-Fallback
bool sdOk = false;
static inline uint64_t storeFree() {
  return sdOk ? (SD_MMC.totalBytes() - SD_MMC.usedBytes()) : FFat.freeBytes();
}

#if __has_include("secrets.h")
#include "secrets.h"
#else
#define WIFI_SSID "SSID_HIER"
#define WIFI_PASS "PASSWORT_HIER"
#endif
#ifndef AP_SSID
#define AP_SSID "TOPIKO"
#define AP_PASS "topiko2026"
#endif

// ====== KONFIGURATION ======
#define DOCK_HOST_HOME "192.168.2.86"  // Dock im Heim-WLAN
#define DOCK_HOST_AP   "10.42.0.1"     // Dock als eigener Hotspot (Ausstellung)
#define DOCK_PORT   5000
#define SAMPLE_RATE 16000
#define MAX_REC_S   20
#define MIN_REC_S   1.0f   // kuerzer = Versehen, wird still verworfen
#define SYNC_EVERY_MS 12000
#define MIC_GAIN_ES7210 ES7210_MIC_GAIN_37_5DB   // Array-Mikro braucht hohe Verstaerkung

// ====== PINS ======
#define LCD_CS 12
#define LCD_SCLK 38
#define LCD_SDIO0 4
#define LCD_SDIO1 5
#define LCD_SDIO2 6
#define LCD_SDIO3 7
#define LCD_RESET 39
#define LCD_W 466
#define LCD_H 466
#define IIC_SDA 15
#define IIC_SCL 14
#define PIN_BCLK 9
#define PIN_WS 45
#define PIN_DI 8       // I2S DOUT des ESP -> ES8311 (Lautsprecher)
#define PIN_DO 10      // I2S DIN  des ESP <- ES7210 (Mikrofon-Array)
#define PIN_MCLK 42
#define PIN_PA 46
#define BTN_PIN   0    // BOOT-Taste (Fallback), aktiv LOW
#define TOUCH_PIN 16   // TTP223 am 8-Pin-Header "16", aktiv HIGH

// ====== Renderer: 232 px intern, 2x hochskaliert auf 464 px (fast vollflaechig) ======
#define CV 232
#define OUTW (CV * 2)                    // 464
#define OUT_X 0
#define OUT_Y 0
#define CX (CV / 2)
#define CY (CV / 2)
#define EDGE_SOFT 16                     // weiche Kante (Renderpixel; wirkt 2x)

// Heller Kern exakt in der Mitte (radialer Verlauf) — damit ist die Optik
// unabhaengig von der Einbaurotation des Displays.
#define LIGHT_DX  0
#define LIGHT_DY  0

Arduino_DataBus *bus = new Arduino_ESP32QSPI(LCD_CS, LCD_SCLK, LCD_SDIO0, LCD_SDIO1, LCD_SDIO2, LCD_SDIO3);
Arduino_CO5300 *gfx = new Arduino_CO5300(bus, LCD_RESET, 0, LCD_W, LCD_H, 6, 0, 0, 0);
XPowersAXP2101 power;
uint16_t *fbSmall = nullptr;             // CV*CV Renderpuffer
#define ROWSPAN 16                       // Ausgabezeilen je QSPI-Push
uint16_t *rowBuf = nullptr;              // ROWSPAN*OUTW im internen DMA-RAM (schneller als PSRAM)

I2SClass i2s;

// ====== Zustaende ======
enum State { ST_IDLE, ST_RECORDING, ST_SAVING, ST_RESULT };
volatile State state = ST_IDLE;
volatile bool  syncBusy   = false;
volatile int   queueCount = 0;
volatile int   dockPending = -1;
volatile bool  wifiOk = false;
WiFiMulti wifiMulti;
String dockHost = DOCK_HOST_HOME;      // wird nach Verbindung je nach SSID gesetzt
volatile float micLevel = 0.0f;          // 0..1, laeuft IMMER (Dauer-Mikrofon)
volatile int batteryPct = -1;            // 0..100 (Ladestand-Warnfarbe), -1 = unbekannt

uint32_t resUntil = 0;                   // Ergebnis-Farbpuls aktiv bis
uint32_t errUntil = 0;                   // Fehler-Farbpuls aktiv bis

// ====== Audio (Task auf Core 0, Mikro dauerhaft offen) ======
int16_t *recBuf = nullptr;
volatile size_t recSamples = 0;
volatile bool   recActive = false;
volatile bool   recDone = true;
volatile int    micChannel = 0;
es8311_handle_t codecHandle = nullptr;
es7210_dev_handle_t es7210 = nullptr;

// Drone-Bestaetigungstoene (Puffer werden in setup() gebaut)
#define DRONE_S ((SAMPLE_RATE * 14) / 10)          // 1,4 s
int16_t *droneSave = nullptr;                      // Notiz gespeichert (tief, A2)
int16_t *droneResult = nullptr;                    // Ergebnis da (heller, D3)
volatile int16_t *dronePending = nullptr;

void audioTask(void *arg) {
  const int FRAMES = 256;                // 16 ms Latenz fuer die Visualisierung
  static int16_t chunk[FRAMES * 2];
  for (;;) {
    size_t got = i2s.readBytes((char *)chunk, sizeof(chunk));
    int frames = got / 4;
    if (frames <= 0) { vTaskDelay(1); continue; }
    uint32_t acc = 0;
    size_t n = recSamples;
    bool rec = recActive;
    for (int i = 0; i < frames; i++) {
      int16_t s = chunk[i * 2 + micChannel];
      acc += (uint32_t)abs(s);
      if (rec && n < (size_t)SAMPLE_RATE * MAX_REC_S) recBuf[n++] = s;
    }
    if (rec) {
      recSamples = n;
      recDone = false;
      if (n >= (size_t)SAMPLE_RATE * MAX_REC_S) recActive = false;
    } else {
      recDone = true;
    }
    // Pegel: schneller Anstieg, langsamer Abfall — wirkt organisch
    float inst = fminf(1.0f, (float)(acc / frames) / 3500.0f);
    micLevel = fmaxf(inst, micLevel * 0.93f);
  }
}

// ====== WAV / Warteschlange (FFat) ======
void writeWavHeader(uint8_t *h, uint32_t dataBytes) {
  uint32_t chunk = 36 + dataBytes, sub1 = 16, sr = SAMPLE_RATE, br = SAMPLE_RATE * 2;
  uint16_t fmt = 1, ch = 1, ba = 2, bps = 16;
  memcpy(h, "RIFF", 4); memcpy(h + 4, &chunk, 4); memcpy(h + 8, "WAVE", 4);
  memcpy(h + 12, "fmt ", 4); memcpy(h + 16, &sub1, 4); memcpy(h + 20, &fmt, 2);
  memcpy(h + 22, &ch, 2); memcpy(h + 24, &sr, 4); memcpy(h + 28, &br, 4);
  memcpy(h + 32, &ba, 2); memcpy(h + 34, &bps, 2);
  memcpy(h + 36, "data", 4); memcpy(h + 40, &dataBytes, 4);
}

int countQueue() {
  int n = 0;
  File dir = store->open("/q");
  if (!dir) return 0;
  File f;
  while ((f = dir.openNextFile())) { if (!f.isDirectory()) n++; f.close(); }
  dir.close();
  return n;
}

bool saveRecording() {
  uint32_t dataBytes = (uint32_t)recSamples * 2;
  if (storeFree() < dataBytes + 65536) return false;
  char id[24];
  snprintf(id, sizeof(id), "hh%08lx%04x", (unsigned long)esp_random(), (unsigned)(millis() & 0xFFFF));
  String path = String("/q/") + id + ".wav";
  File f = store->open(path, FILE_WRITE);
  if (!f) return false;
  uint8_t hdr[44];
  writeWavHeader(hdr, dataBytes);
  f.write(hdr, 44);
  size_t written = 0;
  const size_t CH = 16384;
  uint8_t *p = (uint8_t *)recBuf;
  while (written < dataBytes) {
    size_t k = min(CH, (size_t)(dataBytes - written));
    if (f.write(p + written, k) != k) { f.close(); store->remove(path); return false; }
    written += k;
  }
  f.close();
  queueCount = countQueue();
  Serial.printf("[REC] gespeichert %s (%.1fs, Queue %d)\n", path.c_str(),
                (float)recSamples / SAMPLE_RATE, queueCount);
  return true;
}

// ====== Ergebnis-Farbpuls (Kategorie -> Farbe, KEIN Text) ======
BlobStyle S_RESULT;   // wird je Kategorie gesetzt

void setResultStyle(const String &type) {
  struct { const char *t; uint8_t r1, g1, b1, r2, g2, b2; } M[] = {
    { "termin",     0x4F, 0xC3, 0xF7, 0x06, 0x1E, 0x30 },
    { "todo",       0xFF, 0xB7, 0x4D, 0x38, 0x1E, 0x04 },
    { "erinnerung", 0xBA, 0x68, 0xC8, 0x26, 0x0C, 0x2C },
    { "idee",       0xFF, 0xF1, 0x76, 0x33, 0x2E, 0x06 },
    { "tagebuch",   0x81, 0xC7, 0x84, 0x0C, 0x28, 0x10 },
  };
  // weisser Kern, Kategorie-Farbe als Koerper, abgedunkelte Variante als Glow
  S_RESULT = { 0xFF, 0xEE, 0xF2,  0xB0, 0xBE, 0xC5,  0x40, 0x48, 0x50,
               0.65f, 0.11f, 0.20f, 0.022f, 106 };
  for (auto &m : M) {
    if (type == m.t) {
      S_RESULT.r2 = m.r1; S_RESULT.g2 = m.g1; S_RESULT.b2 = m.b1;
      S_RESULT.r3 = m.r1 * 0.45f; S_RESULT.g3 = m.g1 * 0.45f; S_RESULT.b3 = m.b1 * 0.45f;
      break;
    }
  }
}

// ====== Sync (Core 0): Upload + Ergebnisse zurueckholen ======
bool uploadFile(const String &path) {
  File f = store->open(path, FILE_READ);
  if (!f) return false;
  size_t sz = f.size();
  uint8_t *data = (uint8_t *)ps_malloc(sz);
  if (!data) { f.close(); return false; }
  f.read(data, sz);
  f.close();

  String id = path.substring(3, path.length() - 4);
  float dur = (sz > 44) ? (float)(sz - 44) / (SAMPLE_RATE * 2) : 0;
  String boundary = "----topiko" + String(millis());
  String head = "--" + boundary + "\r\nContent-Disposition: form-data; name=\"id\"\r\n\r\n" + id +
                "\r\n--" + boundary + "\r\nContent-Disposition: form-data; name=\"duration\"\r\n\r\n" + String(dur, 1) +
                "\r\n--" + boundary + "\r\nContent-Disposition: form-data; name=\"audio\"; filename=\"" + id +
                ".wav\"\r\nContent-Type: audio/wav\r\n\r\n";
  String tail = "\r\n--" + boundary + "--\r\n";
  size_t bodyLen = head.length() + sz + tail.length();
  uint8_t *body = (uint8_t *)ps_malloc(bodyLen);
  if (!body) { free(data); return false; }
  memcpy(body, head.c_str(), head.length());
  memcpy(body + head.length(), data, sz);
  memcpy(body + head.length() + sz, tail.c_str(), tail.length());
  free(data);

  HTTPClient http;
  http.begin(String("http://") + dockHost + ":" + DOCK_PORT + "/upload");
  http.setTimeout(20000);
  http.addHeader("Content-Type", "multipart/form-data; boundary=" + boundary);
  int code = http.POST(body, bodyLen);
  free(body);
  String resp = (code > 0) ? http.getString() : "";
  http.end();
  Serial.printf("[SYNC] Upload %s -> %d %s\n", id.c_str(), code, resp.c_str());
  if (code == 200) { store->remove(path); return true; }
  return false;
}

bool fetchResults() {
  HTTPClient http;
  http.begin(String("http://") + dockHost + ":" + DOCK_PORT + "/api/results?limit=3");
  http.setTimeout(8000);
  int code = http.GET();
  if (code != 200) { http.end(); return false; }
  String resp = http.getString();
  http.end();

  JsonDocument doc;
  if (deserializeJson(doc, resp)) return false;
  dockPending = doc["pending"] | -1;
  JsonArray arr = doc["results"].as<JsonArray>();
  if (arr.size() == 0) return true;

  String ids = "", lastType = "unbekannt";
  File log = store->open("/done.jsonl", FILE_APPEND);   // Basis fuer NFC-Sync ans iPhone
  for (JsonObject r : arr) {
    String id = r["id"] | "";
    if (id.isEmpty()) continue;
    if (log) { serializeJson(r, log); log.print("\n"); }
    lastType = String((const char *)(r["type"] | "unbekannt"));
    if (!ids.isEmpty()) ids += ",";
    ids += "\"" + id + "\"";
  }
  if (log) log.close();
  if (ids.isEmpty()) return true;

  setResultStyle(lastType);
  resUntil = millis() + 4500;
  if (state == ST_IDLE) state = ST_RESULT;
  dronePending = droneResult;                      // hellerer Drone: Ergebnis ist da

  HTTPClient ack;
  ack.begin(String("http://") + dockHost + ":" + DOCK_PORT + "/api/ack");
  ack.setTimeout(8000);
  ack.addHeader("Content-Type", "application/json");
  int ac = ack.POST("{\"ids\":[" + ids + "]}");
  ack.end();
  Serial.printf("[SYNC] Ergebnis '%s' geholt, ACK -> %d\n", lastType.c_str(), ac);
  return true;
}

void syncTask(void *arg) {
  uint32_t lastTry = 0;
  for (;;) {
    vTaskDelay(pdMS_TO_TICKS(500));
    wifiOk = (WiFi.status() == WL_CONNECTED);
    if (wifiOk) dockHost = (WiFi.SSID() == AP_SSID) ? DOCK_HOST_AP : DOCK_HOST_HOME;
    if (!wifiOk) {
      static uint32_t lastRe = 0;
      if (millis() - lastRe > 20000) { wifiMulti.run(); lastRe = millis(); }
      continue;
    }
    if (state == ST_RECORDING || state == ST_SAVING) continue;
    if (millis() - lastTry < SYNC_EVERY_MS) continue;
    lastTry = millis();

    syncBusy = true;
    File dir = store->open("/q");
    if (dir) {
      File f = dir.openNextFile();
      String path = "";
      while (f && f.isDirectory()) { f.close(); f = dir.openNextFile(); }
      if (f) { path = String("/q/") + f.name(); f.close(); }
      dir.close();
      if (!path.isEmpty()) {
        uploadFile(path);
        queueCount = countQueue();
        if (queueCount > 0) lastTry = millis() - SYNC_EVERY_MS + 1500;
      }
    }
    fetchResults();
    syncBusy = false;
  }
}

// ====== Herz-Renderer ======
uint8_t *angLUT = nullptr;
uint8_t *radLUT = nullptr;
uint8_t *lightLUT = nullptr;
uint16_t paletteCur[256];
uint8_t contour[256];
uint32_t invContour[256];                // Kehrwert (205<<16)/contour -> spart Division je Pixel
float heartBase[256];                    // Herz-Abstraktion (statisch, einmal berechnet)

// Farbwelt nach Referenzbild: weiss-rosa Kern oben, Orange im Koerper, Pink als Glow.
// Idle: kaum Herzschlag — stattdessen zyklisches Verblassen/Aufloesen ins Korn.
// Aufnahme: kraeftiges Lub-dub, das mit der Stimme mitgeht.
//                     Kern (hell)        Mitte (Koerper)     Rand (Glow)       Periode  Amp    Audio  Unruhe Radius
BlobStyle S_IDLE  = { 0xFF, 0xEC, 0xF4,  0xEE, 0x9C, 0x20,  0xE2, 0x63, 0xBE, 1.55f, 0.020f, 0.10f, 0.008f, 112 };
// Aufnahme: Blob schrumpft deutlich (Radius 72 statt Idle 112) als Sprech-Feedback;
// pulsiert nur noch leicht mit der Stimme, damit er klein bleibt. Rueckweg = Idle-Groesse.
BlobStyle S_REC   = { 0xFF, 0xF2, 0xD8,  0xFF, 0x7A, 0x30,  0xE0, 0x30, 0x50, 0.75f, 0.060f, 0.12f, 0.014f, 72 };
BlobStyle S_PROC  = { 0xEA, 0xE0, 0xFF,  0x9A, 0x6C, 0xF0,  0x4A, 0x2C, 0xB0, 0.95f, 0.065f, 0.10f, 0.024f, 110 };
BlobStyle S_ERR   = { 0xFF, 0xD0, 0xD0,  0xF0, 0x50, 0x50,  0x80, 0x10, 0x20, 0.45f, 0.095f, 0.10f, 0.032f, 110 };
BlobStyle S_SAVED = { 0xFF, 0xFF, 0xF6,  0x9C, 0xE8, 0xC0,  0x2A, 0x70, 0x58, 0.90f, 0.070f, 0.16f, 0.010f, 116 };
// Akku-Warnfarben im Ruhezustand: gleiche ruhige Bewegung wie S_IDLE, nur Farbe rot.
BlobStyle S_LOW20 = { 0xFF, 0xE6, 0xE2,  0xE8, 0x6A, 0x52,  0x90, 0x28, 0x2E, 1.55f, 0.020f, 0.10f, 0.008f, 112 }; // <20% leichtes Rot
BlobStyle S_LOW10 = { 0xF0, 0x60, 0x50,  0xB0, 0x14, 0x10,  0x38, 0x04, 0x06, 1.55f, 0.022f, 0.10f, 0.008f, 112 }; // <10% starkes Dunkelrot
uint32_t savedUntil = 0;   // kurze "gespeichert"-Bestaetigung
float recPeak = 0.0f;      // lautester Pegel waehrend der Aufnahme (Sprach-Gate)
BlobStyle cur     = S_IDLE;

// ====== Idle-Aufloesungszyklus (Verblassen -> Korn -> scharf zurueck) ======
static inline float mixf(float a, float b, float t) { return a + (b - a) * t; }
static inline float smoothf(float t) { return t * t * (3.0f - 2.0f * t); }
float dissolve = 0;                      // 0 = scharf, 1 = komplett im Noise
static uint32_t rng = 0x2F6E2B1u;
static inline uint32_t xrnd() { rng ^= rng << 13; rng ^= rng >> 17; rng ^= rng << 5; return rng; }

float dissolveTarget(float tSec) {
  const float T = 11.0f;                             // Zyklusdauer
  float s = fmodf(tSec, T) / T;
  int cycle = (int)(tSec / T);
  // Tiefe variiert je Zyklus: mal nur Verblassen, mal ganz im Noise verschwinden
  float ph = cycle * 2.399f;
  float depth = 0.45f + 0.55f * (0.5f + 0.5f * sinf(ph));
  // langsam aufloesen (0.32..0.62), kurz weg, schneller scharf zurueck (0.78..0.90)
  float up = smoothf(fminf(1.0f, fmaxf(0.0f, (s - 0.32f) / 0.30f)));
  float dn = smoothf(fminf(1.0f, fmaxf(0.0f, (s - 0.78f) / 0.12f)));
  return depth * up * (1.0f - dn);
}

static inline uint16_t rgb565(uint8_t r, uint8_t g, uint8_t b) {
  return ((r & 0xF8) << 8) | ((g & 0xFC) << 3) | (b >> 3);
}
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
void loop() {
  static uint32_t t0 = millis();
  float tSec = (millis() - t0) / 1000.0f;

  // --- Push-to-talk ---
  // Touch-Entprellung: Pegel muss stabil anliegen, Stoerimpulse werden ignoriert
  static bool     touchStable = false;   // entprellter Zustand
  static bool     rawLast     = false;
  static uint32_t rawSince    = 0;
  bool rawNow = (digitalRead(TOUCH_PIN) == HIGH);
  if (rawNow != rawLast) { rawLast = rawNow; rawSince = millis(); }
  if (rawNow  && !touchStable && millis() - rawSince >= 100) touchStable = true;   // 100 ms stabil HIGH
  if (!rawNow &&  touchStable && millis() - rawSince >= 200) touchStable = false;  // 200 ms stabil LOW
  bool pressed = (digitalRead(BTN_PIN) == LOW) || touchStable;
  static bool wasPressed = false;

  if (pressed && !wasPressed) {
    if (state == ST_IDLE || state == ST_RESULT) {
      recSamples = 0;
      recPeak = 0.0f;
      recActive = true;
      state = ST_RECORDING;
      Serial.println("[REC] Start");
    }
  }
  if (!pressed && wasPressed && state == ST_RECORDING) {
    recActive = false;
    while (!recDone) delay(5);
    float dur = (float)recSamples / SAMPLE_RATE;
    Serial.printf("[REC] Stop (%.2fs)\n", dur);
    // Ausschalten passiert NICHT mehr ueber langes Halten (verwarf faelschlich
    // echte Aufnahmen), sondern nur noch ueber den 5-min-Inaktivitaetstimer.
    if (dur < MIN_REC_S || recPeak < 0.12f) {
      // Versehen oder keine Sprache: still verwerfen
      Serial.printf("[REC] verworfen (%.2fs, Peak %.2f)\n", dur, recPeak);
      state = ST_IDLE;
    } else {
      if (saveRecording()) { dronePending = droneSave; savedUntil = millis() + 1500; }
      else errUntil = millis() + 2800;
      state = ST_IDLE;   // sofort wieder bereit, Verarbeitung laeuft asynchron am Dock
    }
  }
  if (state == ST_RECORDING && micLevel > recPeak) recPeak = micLevel;
  wasPressed = pressed;

  // Auto-Sleep: 5 min Inaktivitaet auf Akku (kein USB) -> Deep Sleep, Touch weckt.
  // (Manuelles Ausschalten per langem Halten wurde entfernt.)
  static uint32_t lastActivity = millis();
  if (pressed || state != ST_IDLE || queueCount > 0 ||
      millis() < savedUntil || millis() < resUntil) lastActivity = millis();
  // Beim Abziehen des USB-Kabels die Leerlaufuhr neu starten, damit das Geraet
  // nicht sofort schlaeft, wenn es vorher schon laenger am Dock geruht hat.
  static bool prevVbus = true;
  bool vbusNow = power.isVbusIn();
  if (prevVbus && !vbusNow) lastActivity = millis();
  prevVbus = vbusNow;
  if (millis() - lastActivity > 300000 && !vbusNow) powerOff();

  // Zwischenstufe vor dem Sleep: auf Akku nach 60 s Ruhe dimmen. Der AMOLED-Strom
  // skaliert stark mit der Helligkeit; bei Beruehrung sofort wieder volle Helligkeit.
  static uint8_t curBright = 255;
  uint8_t wantBright = 255;
  if (pmuOk && state == ST_IDLE && !power.isVbusIn() &&
      millis() - lastActivity > 60000) wantBright = 90;
  if (wantBright != curBright) { gfx->setBrightness(wantBright); curBright = wantBright; }

  if (state == ST_RESULT && millis() > resUntil) state = ST_IDLE;

  // --- Zielstil bestimmen, weich ueberblenden, rendern ---
  BlobStyle *target = &S_IDLE;
  if (state == ST_RECORDING) target = &S_REC;
  else if (millis() < errUntil) target = &S_ERR;
  else if (millis() < savedUntil) target = &S_SAVED;  // kurze Bestaetigung
  else if (state == ST_RESULT) target = &S_RESULT;
  else if (batteryPct >= 0 && batteryPct < 10) target = &S_LOW10;  // <10% Dunkelrot
  else if (batteryPct >= 0 && batteryPct < 20) target = &S_LOW20;  // <20% leichtes Rot

  // Aufloesungszyklus nur im ruhigen Idle; bei Interaktion sofort scharf
  if (target == &S_IDLE || target == &S_LOW20 || target == &S_LOW10)
    dissolve += (dissolveTarget(tSec) - dissolve) * 0.06f;
  else dissolve *= 0.80f;

  blendStyle(*target, 0.10f);

  renderHeart(tSec);
  flushUpscaled();

  static uint32_t frames = 0, lastFps = millis(), lastBat = 0;
  frames++;
  if (millis() - lastFps > 5000) {
    Serial.printf("[UI] %.1f fps, Level %.2f, Heap %u, PSRAM %u\n", frames / 5.0f,
                  micLevel, (unsigned)ESP.getFreeHeap(), (unsigned)ESP.getFreePsram());
    frames = 0; lastFps = millis();
  }
  if (millis() - lastBat > 30000 && state == ST_IDLE) {
    lastBat = millis();
    if (!pmuOk) pmuInit();     // AXP2101 erneut versuchen, falls beim Boot nicht erkannt
    logBattery();
  }
}

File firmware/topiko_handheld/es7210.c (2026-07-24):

/*
 * SPDX-FileCopyrightText: 2022 Espressif Systems (Shanghai) CO LTD
 *
 * SPDX-License-Identifier: Apache-2.0
 */

#include <inttypes.h>
#include <stdlib.h>
#include "es7210.h"
#include "es7210_reg.h"
#include "esp_log.h"
#include "esp_check.h"
#include "esp32-hal-i2c.h"   // Arduino-HAL: teilt sich den Bus mit Wire

const static char *TAG = "ES7210";

#define IS_ES7210_I2S_FMT(val) (((val)==ES7210_I2S_FMT_I2S) || ((val)==ES7210_I2S_FMT_LJ) || \
        ((val)==ES7210_I2S_FMT_DSP_A) || ((val)==ES7210_I2S_FMT_DSP_B))

#define IS_ES7210_I2S_BITS(val) (((val)==ES7210_I2S_BITS_24B) || ((val)==ES7210_I2S_BITS_20B) || \
        ((val)==ES7210_I2S_BITS_18B) || ((val)==ES7210_I2S_BITS_16B) || ((val)==ES7210_I2S_BITS_32B))

#define IS_ES7210_MIC_GAIN(val) (((val) >= ES7210_MIC_GAIN_0DB) && ((val) <= ES7210_MIC_GAIN_37_5DB))

#define IS_ES7210_MIC_BIAS(val) (((val)==ES7210_MIC_BIAS_2V18) || ((val)==ES7210_MIC_BIAS_2V26) || \
        ((val)==ES7210_MIC_BIAS_2V36) || ((val)==ES7210_MIC_BIAS_2V45) || ((val)==ES7210_MIC_BIAS_2V55) || \
        ((val)==ES7210_MIC_BIAS_2V66) || ((val)==ES7210_MIC_BIAS_2V78) || ((val)==ES7210_MIC_BIAS_2V87))

#define ES7210_WRITE_REG(reg_addr, reg_value) do { \
    ESP_RETURN_ON_ERROR(es7210_write_reg(handle, (reg_addr), (reg_value)), \
                        TAG, "i2c communication error while writing "#reg_addr); \
} while(0)

struct es7210_dev_t {
    i2c_port_t  i2c_port;
    uint8_t     i2c_addr;
};

/**
 * @brief Clock coefficient structure
 *
 */
typedef struct {
    uint32_t mclk;            /*!< mclk frequency */
    uint32_t lrck;            /*!< lrck */
    uint8_t  ss_ds;           /*!< not used */
    uint8_t  adc_div;         /*!< adcclk divider */
    uint8_t  dll;             /*!< dll_bypass */
    uint8_t  doubler;         /*!< doubler enable */
    uint8_t  osr;             /*!< adc osr */
    uint8_t  mclk_src;        /*!< select mclk  source */
    uint32_t lrck_h;          /*!< The high 4 bits of lrck */
    uint32_t lrck_l;          /*!< The low 8 bits of lrck */
} coeff_div_t;

/**
 * @brief ES7210 clock coefficient lookup table
 *
 */
static const coeff_div_t es7210_coeff_div[] = {
//    mclk      lrck    ss_ds adc_div  dll  doubler osr  mclk_src  lrckh   lrckl
    /* 8k */
    {12288000,  8000,  0x00,  0x03,  0x01,  0x00,  0x20,  0x00,    0x06,  0x00},
    {16384000,  8000,  0x00,  0x04,  0x01,  0x00,  0x20,  0x00,    0x08,  0x00},
    {19200000,  8000,  0x00,  0x1e,  0x00,  0x01,  0x28,  0x00,    0x09,  0x60},
    {4096000,   8000,  0x00,  0x01,  0x01,  0x00,  0x20,  0x00,    0x02,  0x00},

    /* 11.025k */
    {11289600,  11025,  0x00,  0x02,  0x01,  0x00,  0x20,  0x00,    0x01,  0x00},

    /* 12k */
    {12288000,  12000,  0x00,  0x02,  0x01,  0x00,  0x20,  0x00,    0x04,  0x00},
    {19200000,  12000,  0x00,  0x14,  0x00,  0x01,  0x28,  0x00,    0x06,  0x40},

    /* 16k */
    {4096000,   16000,  0x00,  0x01,  0x01,  0x01,  0x20,  0x00,    0x01,  0x00},
    {19200000,  16000,  0x00,  0x0a,  0x00,  0x00,  0x1e,  0x00,    0x04,  0x80},
    {16384000,  16000,  0x00,  0x02,  0x01,  0x00,  0x20,  0x00,    0x04,  0x00},
    {12288000,  16000,  0x00,  0x03,  0x01,  0x01,  0x20,  0x00,    0x03,  0x00},

    /* 22.05k */
    {11289600,  22050,  0x00,  0x01,  0x01,  0x00,  0x20,  0x00,    0x02,  0x00},

    /* 24k */
    {12288000,  24000,  0x00,  0x01,  0x01,  0x00,  0x20,  0x00,    0x02,  0x00},
    {19200000,  24000,  0x00,  0x0a,  0x00,  0x01,  0x28,  0x00,    0x03,  0x20},

    /* 32k */
    {12288000,  32000,  0x00,  0x03,  0x00,  0x00,  0x20,  0x00,    0x01,  0x80},
    {16384000,  32000,  0x00,  0x01,  0x01,  0x00,  0x20,  0x00,    0x02,  0x00},
    {19200000,  32000,  0x00,  0x05,  0x00,  0x00,  0x1e,  0x00,    0x02,  0x58},

    /* 44.1k */
    {11289600,  44100,  0x00,  0x01,  0x01,  0x01,  0x20,  0x00,    0x01,  0x00},

    /* 48k */
    {12288000,  48000,  0x00,  0x01,  0x01,  0x01,  0x20,  0x00,    0x01,  0x00},
    {19200000,  48000,  0x00,  0x05,  0x00,  0x01,  0x28,  0x00,    0x01,  0x90},

    /* 64k */
    {16384000,  64000,  0x01,  0x01,  0x01,  0x00,  0x20,  0x00,    0x01,  0x00},
    {19200000,  64000,  0x00,  0x05,  0x00,  0x01,  0x1e,  0x00,    0x01,  0x2c},

    /* 88.2k */
    {11289600,  88200,  0x01,  0x01,  0x01,  0x01,  0x20,  0x00,    0x00,  0x80},

    /* 96k */
    {12288000,  96000,  0x01,  0x01,  0x01,  0x01,  0x20,  0x00,    0x00,  0x80},
    {19200000,  96000,  0x01,  0x05,  0x00,  0x01,  0x28,  0x00,    0x00,  0xc8},
};

/**
 * @brief Get coefficient from coefficient table
 *
 * @param mclk Desired MCLK value
 * @param lrck Desired LRCK vaule
 * @return Coefficient struct, NULL if desired value cannot be achieved
 */
static const coeff_div_t *es7210_get_coeff(uint32_t mclk, uint32_t lrck)
{
    for (int i = 0; i < sizeof(es7210_coeff_div) / sizeof(coeff_div_t); i++) {
        if (es7210_coeff_div[i].lrck == lrck && es7210_coeff_div[i].mclk == mclk) {
            return &es7210_coeff_div[i];
        }
    }
    return NULL;
}

static esp_err_t es7210_write_reg(es7210_dev_handle_t handle, uint8_t reg_addr, uint8_t reg_val)
{
    ESP_RETURN_ON_FALSE(handle, ESP_ERR_INVALID_ARG, TAG, "invalid device handle");
    uint8_t buf[2] = { reg_addr, reg_val };
    return i2cWrite(handle->i2c_port, handle->i2c_addr, buf, 2, 1000);
}

#if 0   /* Original-Implementierung (Legacy-I2C-Treiber, kollidiert mit Wire) */
static esp_err_t es7210_write_reg_legacy(es7210_dev_handle_t handle, uint8_t reg_addr, uint8_t reg_val)
{
    ESP_RETURN_ON_FALSE(handle, ESP_ERR_INVALID_ARG, TAG, "invalid device handle");
    esp_err_t ret = ESP_OK;

    i2c_cmd_handle_t cmd = i2c_cmd_link_create();
    ESP_GOTO_ON_FALSE(cmd, ESP_ERR_NO_MEM, err, TAG, "memory allocation for i2c cmd handle failed");

    ESP_GOTO_ON_ERROR(i2c_master_start(cmd), err, TAG, "error while appending i2c command");
    ESP_GOTO_ON_ERROR(i2c_master_write_byte(cmd, handle->i2c_addr << 1 | I2C_MASTER_WRITE, true),
                      err, TAG, "error while appending i2c command");
    ESP_GOTO_ON_ERROR(i2c_master_write_byte(cmd, reg_addr, true), err,
                      TAG, "error while appending i2c command");
    ESP_GOTO_ON_ERROR(i2c_master_write_byte(cmd, reg_val, true), err,
                      TAG, "error while appending i2c command");
    ESP_GOTO_ON_ERROR(i2c_master_stop(cmd), err, TAG, "error while appending i2c command");

    ESP_GOTO_ON_ERROR(i2c_master_cmd_begin(handle->i2c_port, cmd, pdMS_TO_TICKS(1000)),
                      err, TAG, "error while writing register");
err:
    if (cmd) {
        i2c_cmd_link_delete(cmd);
    }
    return ret;
}
#endif  /* Ende Legacy-Implementierung */
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

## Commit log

2026-07-24 Initial commit: TOPIKO Open-Source-Release (Firmware, Dock-Software, 3D-Daten, Dokumentation)
    [Akku.step, Display.step, ESP-Board.step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]
2026-07-24 Modell-Link eingetragen: Hugging Face colin18054/TOPIKO-LFM2.5-350M-GGUF
    [Gehäuseeinsatz.step]

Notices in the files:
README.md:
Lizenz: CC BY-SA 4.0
